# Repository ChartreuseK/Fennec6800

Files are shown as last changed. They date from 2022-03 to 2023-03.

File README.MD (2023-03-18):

# Fennec 6800
A Motorola 6800 Based Expandable Single Board Computer

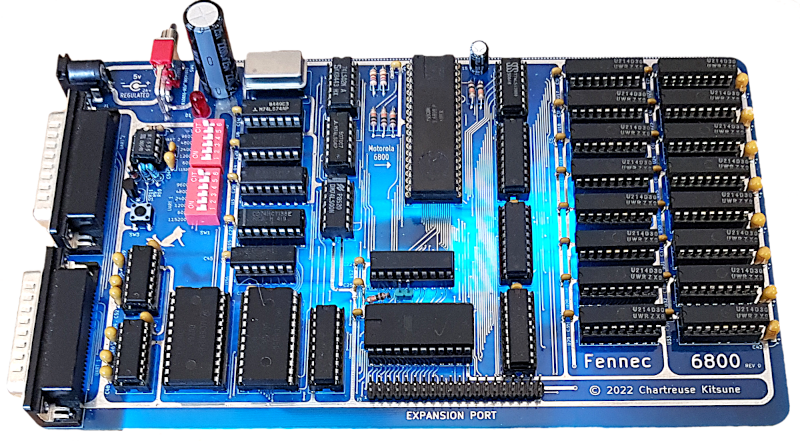
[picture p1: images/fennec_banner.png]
Picture of an Assembled Fennec 6800 Computer


## Introduction
The Fennec 6800 is a Motorola 6800 based single board computer (SBC) created with the inspiration of targeting 1977 components and features. It features an original Motorola 6800 processor running at whopping 921.6kHz, 8kB of the latest 2114 SRAM, 2kB of ROM using the brand new 2716 EPROM, and dual serial ports. An optional 40 pin expansion bus allows for connectivity to other modules, such as the Fennec VTI video terminal interface board, or to create your own attachments.

## Specifications
* Motorola 6800 @ 921.6kHz
* 1-8kB of onboard SRAM using pairs of 2114 (1k x 4 bit) SRAM chips. Using the optional RAM adapter board up to 32kB of RAM can be fitted with minimal modifications
* 2kB, 2716 EPROM containing the Fennec Monitor. Optional support for a 4kB 2732 EPROM
* Dual 6850 ACIA, RS-232 UART connected to dual 25 pin EIA-232 ports in DTE wiring.
* Selectable serial baud rates via DIP switches from 600-9600 baud + 115,200 in default /16 mode, 150-2400+28,800 in /64 mode when configured. Non-standard baud rates are possible using a different master oscillator, but CPU speed will be affected.
* Single rail design. Requires only a 5v regulated source of power.
* 40 pin expansion bus with pre-decoded expansion board select signals, allowing for quite prototyping of custom expansions.
* Beautiful blue PCB with exposed traces for a refined look.
* Compact Board design, only 8.6×5.2 inches!

The Fennec 6800 includes a capable and expandable ROM monitor built in, requiring no tedious toggling of front panel switches to enter and begin executing code. Only a terminal is required to begin making use of the system, simply hook the terminal up to the bottom serial port (furthest from the power jack). This serial port is the local console port in the default system, all traffic is normally routed through this port, though inside the monitor certain commands may be redirected to the auxiliary port located above it.

The monitor provides facilities for examining memory, depositing values into memory, jumping to code in memory, receiving a binary over the XMODEM protocol into RAM, and dumping a block of RAM over the XMODEM protocol. With these facilities and an appropriate host system, program development can be done remotely and loaded into the Fennec to speed up initial system bring-up and testing, or development can be done in the traditional way on paper then loaded in in hexadecimal into the program memory and tested out using the computer.

The monitor also provides support for option ROMs. These option ROM images can be mapped into any of the expansion regions in upper memory starting at a multiple of 0x1000. If detected they can hook into the monitor to provide future expandability and extra features, such as the Fennec VTI board which uses an option ROM to redirect the default terminal from the first serial port to a video display and asci keyboard interface, allowing for standalone use. Future cards may also use this facility to add additional commands such as providing for a rudimentary disk operation system for example.

## Manual
The file Fennec6800_Manual.pdf contains a more comprehensive manual of the Fennec, including some theory of operation as well as assembly hints and guides. Importantly if building a REV 0 board the bodeges required for correct operation are described. The primary bodge required is changing how the data bus buffer is selected, instead of being controlled by only the CPU it is decoded in a way to allow expansion boards to enable the buffer. The KiCAD schematics reflect the changes already made, however the gerbers and rev0 pcb file don't contain the fix.

## BOM 
The complete BOM can be found in either the manual, or in the spreadsheet Fennec6800_BOM.csv 
The BOM contains the reference designators, quantity, a description of the part, as well as one or more suitable Digikey part numbers. The CPU, ACIA/UARTs, and 2716/28C16 EPROM/EEPROM however need to be aquired from secondary sources as they have not been manufactured in some time. The CPU needs to be a MC6800 or direct compatible, note a 6802 has a different pinout and is not drop in compatible. The ACIAs are MC68B50 or similar UARTs, the B variant is not needed for the lower speeds, however a Hitachi 63B50 (2MHz rated) would be required for 115,200 board operation to not be overclocking the chip slightly. This speed however is honestly faster than the Fennec 68000 is really designed for, and at 9600 baud any variant is fine. For the EPROM any speed grade 2716 or 28C16 or equivalent 2kB (8-bit) EPROM/EEPROM is suitable. 2732 EPROMs may also be used, and the extra space can be mapped by installing the jumper next to the ROM socket, however the monitor would need to be reassembled to take advantage of the extra space.

## Burning the ROM
The 2716 EPROM on the Fennec 6800 should be burned with the file `software/monitor/monitor.bin`. This file is in a flat binary format suitable for burning onto a 2kB EPROM. If your program needs Intel HEX or Motorola SREC format it will need to be converted first. The ORG address is F800 (upper 2kB of address space). 

2716 EPROMs are single supply EPROMs, however they need a programmer capable of a 26v programming voltage. The common TL866CS/A is only capable of 21v, and the newer TL866II+ is only capable of 18v max, and won't be able to program the EPROM. For a more convient option there exists the 28C16 EEPROM which is pin compatible and can be programmed with only 5v and is suitable for either TL866 programmer, or even possibly with an Arduino and some custom code. The 28C16 is no-longer newly manufactured but can be fairly readilly sourced. Alternatively using a pin adapter a 28-pin 28C64 (still sold new on Digikey/Mouser from Atmel) can be converted to the 28C16 24-pin pinout. 

## Assembling the Monitor
The monitor source code is designed to be assembled with the cross-platform [AS macro assembler](http://john.ccac.rwth-aachen.de:8000/as/). It may be possible to assemble with other assemblers supporting the 6800, but some changes to the local label syntax may be required. The output of the macro assembler is it's own p file format which can then be converted using p2bin or p2hex to a suitable output format.

    asl -L monitor.asm && p2bin monitor.p
## Expansions

### 62256 RAM Adapter
In the folder Fennec 62256 RAM Adapter you can find a second PCB which allows the use of common and still in production 62256 (32k x 8) SRAM chips in place of the vintage and hard to source 2114 sram that the Fennec is designed for. This board slots into the top two ram sockets as well as the 74LS138 socket to provide the full 8kB of RAM that the board is designed for. Optionally A13 and A14 may be run to this adapter board to give the Fennec 32kB of RAM, more than normally designed for. 

### Fennec VTI
The [Fennec VTI](https://github.com/ChartreuseK/Fennec6800_VTI) is a 64x16 line text terminal interface with parallel ascii keyboard to provide a local terminal for the Fennec. It negates the need for an external serial terminal, or terminal emulator, making the Fennec into a self contained system. Using the extra port on the PIA on this card, combined with protoboard space, also allows it to be used for experimentations and developing hardware.

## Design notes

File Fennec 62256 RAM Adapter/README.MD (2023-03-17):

# Fennec 6800 62256 RAM Adapter

This adapter allows the use of common 62256 32k x 8-bit SRAM chips with the Fennec 6800, replacing the vintage 2114 SRAM chips. The adapter plugs into the top two SRAM sockets as well as the 74LS138 socket (replacing the IC) and provides a full 8kB of SRAM to the Fennec. Optionally wires may be soldered down to the main board to grab A13 and A14 and soldered to the ram adapter. This modification would allow for the maximum of 32kB of RAM to be fitted to the system, more than normally possbile.

BOM:

* 1x 62256 SRAM - DIP 28
* 1x 74LS02 - DIP 14
* 1x 74LS08 - DIP 14
* 3x 0.1uF 50v X7R Ceramic Capacitors 0.1" pin spacing
* 2x 1k ohm 1/4W carbon film resistor, through hole
* 2x 1x40 pin male machine pin breakaway header. 
  * (16 + 18 + 18 + 9) = 61 pins required.
* Optional 1x40 male square pin header for jumpers. 2 + 3 + 3
* Optional 3x jumper shorting connectors
* 2x DIP 14 socket
* 1x DIP 28 wide (0.6") socket

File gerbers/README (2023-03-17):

# Gerbers for Fennec 6800 board
The plainmask suffixed files contain "normal" solder masks, traces are covered in solder mask as with normal PCBs, this is not the intended look for the Fennec but is provided as an option if people wish. This is the output you get when plotting out the gerber files from KiCAD.

The _exposedtraces_ suffixed files have had the _Cu gerber files copied overtop the _Mask gerber files, this results in all traces and copper on the board being exposed, but the rest of the board being covered in solder mask, resulting in the Fennec's unique look. This is the gerbers you probably want if you're recreating it.

# Creating your own gerbers

If you're making changed in KiCAD and want to get this look, simply copy the two Cu gerber files overtop the corresponding mask file. 
eg.
cp Fennec6800-B_cu.gbl Fennec6800-B_Mask.gbs
cp Fennec6800-F_cu.gbl Fennec6800-F_Mask.gbs

If not using protel extensions the file names will be different but the concept is the same. 

Keep in mind that and custom "keep-out" regions on the mask layers will be lost when doing this. A more complex technique of copying the copper paths to the mask layer in KiCAD would need to be done to preserve them, or hand editing of the gerber code. As the Mask layers in gerber files are inverse, ie. the file specifies where NOT to put soldermask, this results in all copper on the board being left exposed with only the bare FR4 part of the board being covered in the solder mask.

If your PCB fab has access to dyed FR4 board, an even better option is then to eliminate the masks entirely, either by communicating with the fab and asking for no solder mask, or in KiCAD adding a "keep out" box that covers the entire board on both Mask layers. This would result in the "true" intention look of the Fennec if you have access to blue dyed FR4 board.

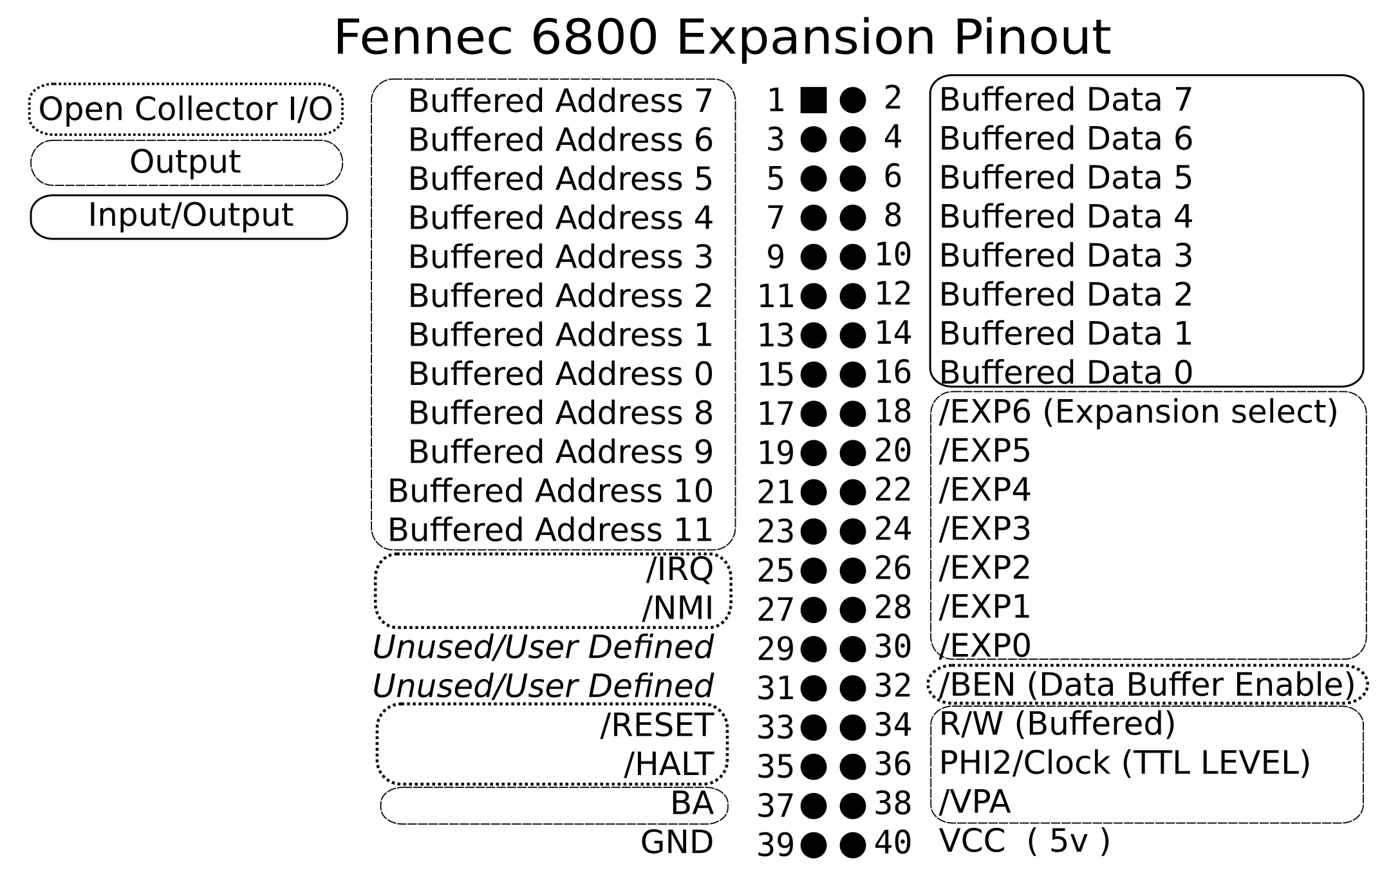
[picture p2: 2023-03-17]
Fennec6800_ExpansionPinout.png

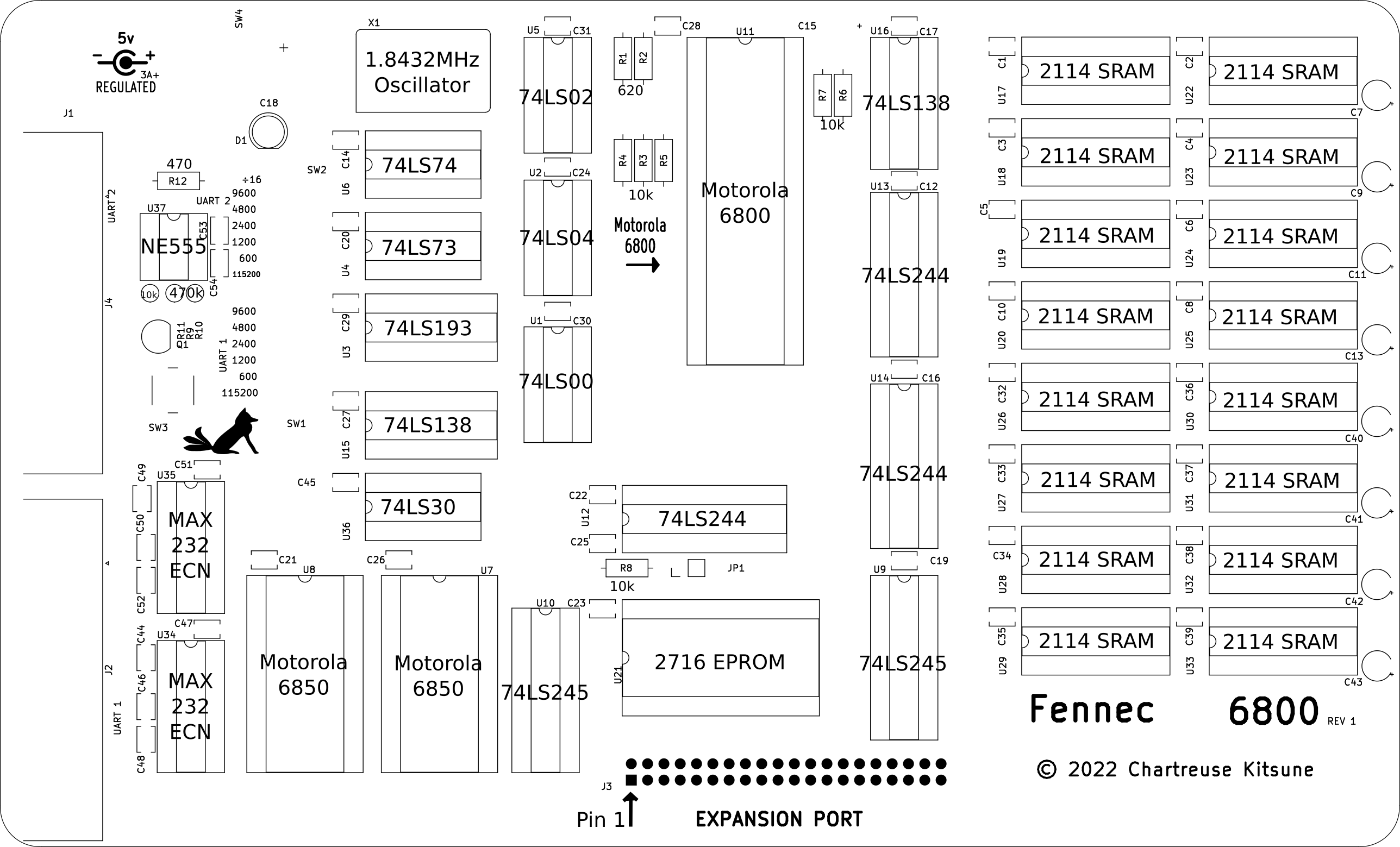
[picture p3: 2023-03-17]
Fennec6800_IC_Diagram.png

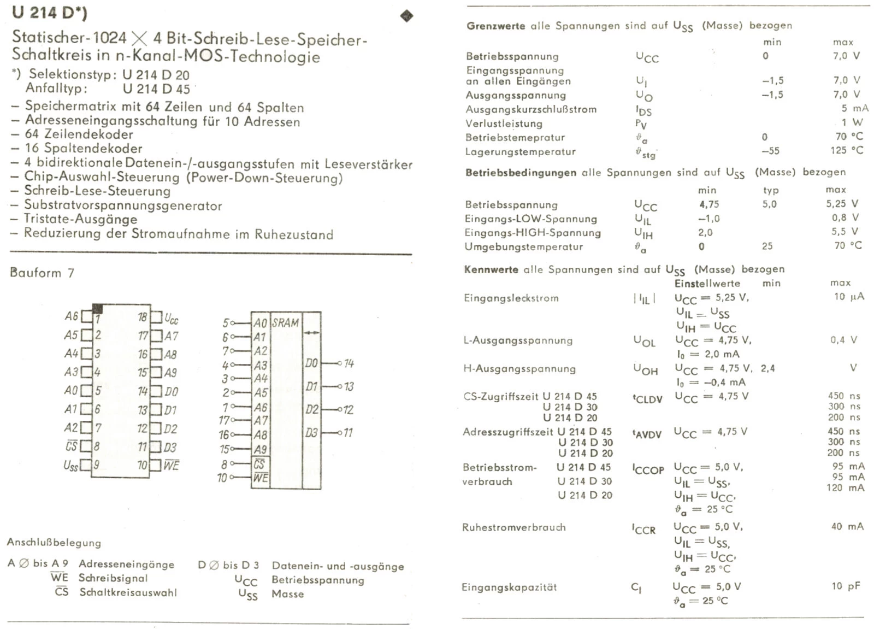
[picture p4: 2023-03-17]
datasheets/U214D.webp

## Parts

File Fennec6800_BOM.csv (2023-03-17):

Reference Designators | Qty. | Part | Digikey Part # | Alternative Digikey Part # (ICs are HCT instead of LS)
C1, C2, C3, C4, C5, C6, C8, C10, C12, C14, C16, C17, C19, C20, C21, C22, C23, C24, C25, C26, C27, C28, C29, C30, C31, C32, C33, C34, C35, C36, C37, C38, C39, C45, C53 | 35 | 0.1uF 50v Ceramic Capacitor, .1” pin pitch | 399-14036-1-ND
C7, C9, C11, C13, C40, C41, C42, C43 | 8 | 10uF 16v Tantalum Capacitor, .1” pin pitch | 478-TAP106K016CRSCT-ND
C15 | 1 | 100uF 16v Aluminum Electrolytic. .1” pin pitch, diameter < 6.3mm | P19632CT-ND
C18 | 1 | 470uF 16v Aluminum Electrolytic. 5mm pin pitch, diameter <13mm | P12375-ND
C44, C46, C47, C48, C49, C50, C51, C52, C56, C55, C56 | 11 | 1.0uF 50v X5R Ceramic Capactior, .1” pin pitch | 445-173257-1-ND | 478-11561-1-ND
D1 | 1 | T1-3/4 (5mm) low-brightness red LED | 160-1707-ND
D2 | 1 | 1N4148 DO-3 diode | 1N4148FS-ND
J1 | 1 | Barrel_Jack, 2.1mm x 5.5mm | CP-202A-ND | CP-102A-ND
J2, J4 | 2 | DB25 Male, right angle board mount. 7.7mm pin edge offset, 9.12mm mounting hole offset | 2057-DB25-PL-24-ND
J3 | 1 | 2x20 0.1” male pin header | 10129381-940002BLF-ND | S2011EC-40-ND
JP1 | 1 | 1x2 0.1” male pin header | 2057-PH1-02-UA-ND | S1011EC-40-ND
Q1 | 1 | 2N3904-AP TO-92 package with stagered center pin | 2N3904BU | 2N3904-AP
R1, R2 | 2 | 620 ohm 1/4W 5% Carbon Film | 620QBK-ND
R3, R4, R5, R6, R7, R8, R13 | 8 | 10k ohm 1/4W 5% Carbon Film | CF14JT10K0CT-ND
R9, R10 | 2 | 470k ohm 1/4W 5% Carbon Film | CF14JT470KCT-ND
R12 | 1 | 470 ohm 1/4W 5% Carbon Film | CF14JT470RCT-ND
SW1, SW2 | 2 | DIP-12, 6 pole DIP switch, 0.3” spacing | 2449-KG06E-ND
SW3 | 1 | 6mm through hole push button | 679-2428-ND
SW4 | 1 | ESWITCH 100SP1T2B4M7QE right angle toggle switch or compatible, SPDT switch | EG5419-ND
U1 | 1 | 74LS00 DIP | 296-1626-ND | 296-1603-5-ND
U2 | 1 | 74LS04 DIP | 296-1629-5-ND | 296-1605-5-ND
U3 | 1 | 74LS193 DIP | 296-1605-5-ND | 296-2142-5-ND
U4 | 1 | 74LS73 DIP | 296-26520-5-ND | 296-3541-5-ND
U5 | 1 | 74LS02 DIP | 296-1627-5-ND | 296-3541-5-ND
U6 | 1 | 74LS74 DIP | 296-1668-5-ND | 296-1605-5-ND
U7, U8 | 2 | MC6850 (68A50/68B50/6350/63A50/63B50) DIP | Vintage, eBay
U9, U10 | 2 | 74LS245 DIP | 296-1655-5-ND | 296-2105-5-ND
U11 | 1 | MC6800 Microprocessor | Vintage, eBay
U12, U13, U14 | 3 | 74LS244 DIP | 296-1653-5-ND | 296-1610-5-ND
U15, U16 | 2 | 74LS138 DIP | 296-1639-5-ND | 296-1608-5-ND
U17, U18, U19, U20, U22, U23, U24, U25, U26, U27, U28, U29, U30, U31, U32, U33 | 16 | P2114 SRAM DIP-18 | Vintage, eBay
U21 | 1 | 2716 EPROM or 28C16 EEPROM | Vintage, eBay
U34, U35 | 2 | MAX232ECN or similar DIP | 296-26139-5-ND
U36 | 1 | 74LS30 DIP | 296-3693-5-ND | 296-2111-5-ND
U37 | 1 | NE555P DIP | 296-NE555P-ND | ICM7555IPAZ-ND
X1 | 1 | 1.8432MHz Full-can (DIP-14) oscillator | X939-ND | 110-MXO45-3C-1M843200-ND
X1 Socket | 1 | DIP-14 (0.3”) crystal socket | ED90428-ND
U7, U8, U21 Socket | 3 | DIP-24 (0.6”) socket | 1175-2554-ND
U9, U10, U12, U13, U14 Socket | 5 | DIP-20 (0.3”) socket | AE9998-ND
U11 Socket | 1 | DIP-40 (0.6”) socket | ED3033-ND
U1, U2, U4, U5, U6, U36 Socket | 6 | DIP-14 (0.3”) socket | 2057-ICS-314-T-ND
U3, U15, U16, U34, U45 | 5 | DIP-16 (0.3”) socket | AE9992-ND
U17, U18, U19, U20, U22, U23, U24, U25, U26, U27, U28, U29, U30, U31, U32, U33 Socket | 16 | DIP-18 (0.3”) socket | 2057-ICS-318-T-ND

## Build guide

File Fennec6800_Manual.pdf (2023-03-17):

# Fennec 6800

## A Motorola 6800 Based Expandable Single Board Computer

## Designed By: Chartreuse

2022-2023

Manual Revision 1.0 – March 2023 | Fennec 6800 User Manual

Dedicated to the Retro Dreams Discord Server for all the help and discussions over the years.

## Introduction

The Fennec 6800 is a Motorola 6800 based single board computer (SBC) created with the inspiration of targeting 1977 components and features. It features an original Motorola 6800 processor running at whopping 921.6kHz, 8kB of the latest 2114 SRAM, 2kB of ROM using the brand new 2716 EPROM, and dual serial ports. An optional 40 pin expansion bus allows for connectivity to other modules, such as the Fennec VTI video terminal interface board, or to create your own attachments.

## Specifications

- Motorola 6800 @ 921.6kHz
- 1-8kB of onboard SRAM using pairs of 2114 (1k x 4 bit) SRAM chips. Using the optional RAM adapter board up to 32kB of RAM can be fitted with minimal modifications
- 2kB, 2716 EPROM containing the Fennec Monitor. Optional support for a 4kB 2732 EPROM
- Dual 6850 ACIA, RS-232 UART connected to dual 25 pin EIA-232 ports in DTE wiring.
- Selectable serial baud rates via DIP switches from 600-9600 baud + 115,200 in default /16 mode, 150-2400+28,800 in /64 mode when configured. Non-standard baud rates are possible using a different master oscillator, but CPU speed will be affected.
- Single rail design. Requires only a 5v regulated source of power.
- 40 pin expansion bus with pre-decoded expansion board select signals, allowing for quite prototyping of custom expansions.
- Beautiful blue PCB with exposed traces for a refined look.
- Compact Board design, only 8.6×5.2 inches!

The Fennec 6800 includes a capable and expandable ROM monitor built in, requiring no tedious toggling of front panel switches to enter and begin executing code. Only a terminal is required to begin making use of the system, simply hook the terminal up to the bottom serial port (furthest from the power jack). This serial port is the local console port in the default system, all traffic is normally routed through this port, though inside the monitor certain commands may be redirected to the auxiliary port located above it.

The monitor provides facilities for examining memory, depositing values into memory, jumping to code in memory, receiving a binary over the XMODEM protocol into RAM, and dumping a block of RAM over the XMODEM protocol. With these facilities and an appropriate host system, program development can be done remotely and loaded into the Fennec to speed up initial system bring-up and testing, or development can be done in the traditional way on paper then loaded in in hexadecimal into the program memory and tested out using the computer.

The monitor also provides support for option ROMs. These option ROM images can be mapped into any of the expansion regions in upper memory starting at a multiple of 0x1000. If detected they can hook into the monitor to provide future expandability and extra features, such as the Fennec VTI board which uses an option ROM to redirect the default terminal from the first serial port to a video display and asci keyboard interface, allowing for standalone use. Future cards may also use this facility to add additional commands such as providing for a rudimentary disk operation system for example.

Manual Revision 1.0 – March 2023 | 2 | Fennec 6800 User Manual

## Design Goals

My goal with the Fennec 6800 was the idea of making a computer mostly within the constraints of the very early days of the personal computer movement. I originally planned to target around 1975 to 1976, however a major difficulty of that era is the available types of EPROMS. The venerable 1702A
EPROM introduced in 1971 only provides 256 bytes of storage, but more importantly requires a +5v and -9v rail to operate, and +10v,+47v, and +59v to program. Without a suitable programmer this chip was right out. Next option was the 2704 and 2708 EPROMs, introduced in 1975 at 512 bytes and 1kB respectively these would be fairly suitable to implement a monitor. However like the 1502 these require split rail power supplies to even operate, +5, -5v, and 12v for both, and 26v to program. Not wanting to require a split rail power system I needed to look forward again. Enter the 2716 EPROM, introduced in 1977 and being one of, if not the first, EPROM to work with a single +5v supply, and giving us a generous 2kB of space.

This set the target date for my system, 1977, two years after the venerable Altair 8800, one year after the Sol-20, and the same year that the personal computer trio launched; the TRS-80, Commodore PET, and the first Apple ][ launching the same year. Now this is a loose goal as I will soon demonstrate, but gives me a focus onto what I want the capabilities to be and roughly how those should be aimed at. One major cheat to this on the board was the use of MAX232 serial level shifters, a chip from 1988. This was more for convenience and not needing to introduce split rail power for the more period MC1488/MC1489 shifters, or discrete transistor circuits also common.

In keeping with the target date, RAM needed to be limited. Now it’s tempting with a modern
homebrew to just slap 64kB or more on these 8-bit systems and be done with it, however in fitting with the era I wanted something a bit more humble. I figured that 8kB was a suitable amount of RAM, with the system being capable of working with as little as 1kB fitted. For RAM I went with the 2114 SRAM chip, also from 1977. While it would not have been the most economical RAM chip of that era, it was the most simple to interface with. It requires only a single rail 5v supply, and no refresh or multiplexing circuitry. Another reason for the choice was that I was able to source twenty of these chips relatively cheaply from an eBay seller and it was part of the inspiration for the project.

Now you may think that only 8kB of RAM seems rather limited, and really it’s not that bad for the era. Sure bigger systems were around, but many of the home computers and kits available at that time would be lucky to have 8kB. The Altair 8800 in bare form shipped with only 256 bytes, though if you were running BASIC you’d likely have at least one 8kB ram expansion for it. Even for 1977, the lowest spec Apple ][ came with a whopping 4kB of RAM, and as RAM was quite expensive, not many people would have opted to max the Apple ][ out with 48kB. The TRS-80 Model 1 also only came with 4kB as standard, same with the PET ][. So 8kB on the Fennec is plenty in line with the competition and other computers of the era, even if RAM prices started falling quickly afterwards.

Part of design was this would be my first homebrew computer created on a PCB in KiCAD without prototyping it on a protoboard or breadboard. Care was put into the schematics and overall design, built on experience with my prior homebrew computer projects and lessons learned from them. This resulted in a computer that required only a small handful of bodge wires to get it working. A resistor was pulled the wrong voltage rail on the ROM. One of the serial baud rates was connected to the wrong point, resulting in the wrong indicated baud, and one bus buffer was connected in a way that made the

Manual Revision 1.0 – March 2023 | 3 | Fennec 6800 User Manual

expansion port unable to drive the bus. The third error being corrected by using a diode and a spare pin on the BUS to create a bus enable input.

In fitting with the design period goals, my aesthetic intentions were to make the board look like some period boards of the time, specifically the blue FR4 with exposed traces look of some Solid State Music and Vector protoboards of the era. Blue dyed FR4 is not really an option at any of the major board houses, especially the cheap ones, however I had learned of a trick from Glitch, who used the concept on his recreation of a Solid State Music board. The trick being to copy the copper layers into the Gerber files of the solder mask layers. This would result in the copper being entirely exposed, with solder mask everywhere but the copper. This is due to the solder mask Gerber files being an inverse mask. Using this with blue solder mask results in the board with some of the appearance of blue dyed FR4, though with a slightly more shiny finish and more translucency of the board. However the end result is simply stunning in appearance.

One downside of course is that all traces are exposed, resulting in more chances of metal contact resulting in a short, or solder splashes shorting some traces. However this can be avoided by being extra careful during soldering, and double checking for shorts after assembling. Shorts can then simply be wicked away with solder braid. As for the former, I’d recommend placing the board in a protective case, perhaps with a clear top to allow the board design to be clearly seen.

Manual Revision 1.0 – March 2023 | 4 | Fennec 6800 User Manual

## Theory of Operation

### Clock Generator

The MC6800 requires two two clock signals, ϕ1 and ϕ2, to be rail-to-rail, non-overlapping inverse

clock signals, ie. 180 degrees out of phase. The tricky part here being the non-overlapping part,

preventing the use of just a simple inverter to put the clocks out of phase. A simple inverter would

satisfy the 180 degrees out of phase part, mostly, but the second clock would be overlapping with the

first by the propagation of a 74LS04 gate delay, approximately 7-15ns.

Motorola recommends the use of the MC6875 clock generator to provide the required ϕ1 and ϕ2 clock

inputs. However this chip is difficult to track down nowadays and would add another obstacle to

building the Fennec by requiring another vintage chip. Furthermore, even in it’s time the chip was

rather expensive, so designers would be apt to avoid it if they didn’t need the additional functionality it

offered besides driving the clock signal. For these reasons I chose to forgo this chip, and instead settled

on driving the clock myself.

To generate these non-overlapping clocks without the MC6875 we need just a simple circuit to

generate a non-overlapping inverted signal. A pair of NOR gates are wired to form a simple RS flip

flop, with a simple square wave clock signal going into the set input. The reset input is connected via

an inverter to the clock signal as well. This inverter between the set and reset inputs helps to insure the

non-overlapping condition through it’s own gate delay. With this the output of the NOR gate connected

to the set input will always change it’s state before that of the one on the reset input. Thus ensuring that

both clock inputs are never high at the same time, the ~10ns gate delay of the 74LS04 providing a

period where both clocks will be low before any rising edge.

### UART decoding

In the name of future expandability, as the /EXP0 is brought out to the bus, the two UARTs are fairly

tightly decoded on the system board, taking up only 16-bytes of the entire address space. While the

upper address space is decoded into 8 equal 4kB regions called EXP6 to EXP0 as well as the ROM

region, it feels appropriate to not waste address space on partial decoding of the UARTs.

The UARTs are thus decoded with a combination of signals. First A11 to A4 are NAND-ed together to

create a signal limiting it to the top 16 bytes of any given 4kB segment, this signal is then inverted

before going to the active-high CS1 chip selects of the 6850 UARTs. The active-low chip select CS2 is

fed by the /EXP0 selection signal, thus now limiting both UARTs to the $EFFx address space. Finally

to differentiate the two UARTs, one is fed A1 on its final CS0 active high chip select, and the other is

fed the inverse of A1 on its CS0 chip select.

This results in a slight partial decoding as the UARTs only require 2 bytes of address space each, but

will be mirrored 4 times within the 16-byte space that they are decoded.

Manual Revision 1.0 – March 2023 | 5 | Fennec 6800 User Manual

### UART Clock Generation

The UART clock rates were an important factor in deciding the overall clock speed of the system. The

CPU speed was desired to be as close to the maximum 1MHz permitted by a plain MC6800 as

possible, however I only wished to use a single oscillator for the entire system. The standard

1.8432MHz baud rate oscillator was thus chosen to be master oscillator for the system. When divided

in half we get a 921.6kHz clock, very close to the maximum 1MHz for the CPU.

1.8432MHz also is extremely useful as a baud rate clock, with no external division and just relying on

the 6850 ACIAs internal /16 mode for asynchronous serial we get 115,200 baud. Too fast for our time

period and liking, but a useful modern serial baud rate. The magic however happens when we further

divide the clock down. First we divide the 921.6kHz CPU clock down by 6. To accomplish this we use

a 74LS73 dual-JK flip flop in a divide by three configuration. The output of this configuration is not a

50% duty cycle however so we divide that again by 2 using a 74LS74 D flip flop to return the duty

cycle to 50%. This brings us to a total of 1.8432MHz / 12 or 153.6kHz. When this baud rate is divided

by 16 in the UART that results in our first usable standard baud rate of 9600.

From 9600 it’s then just a matter of using a 4-bit binary counter to further divide this down into usable

baud rates. 4800, 2400, 1200, and 600 are derived this way. We can also take advantage of the /64

mode of the 6850 UART to get an additional set of 6 baud rates to select form. 115,200 becomes

28,800. 9600 becomes 2400, 4800 becomes 1200, 2400 becomes 600, 1200 becomes 300, and 600

becomes 150. This gives us the standard set of serial baud rates from 150 to 9600 baud to chose from,

in addition to the faster standards of 38,400 and 115,200.

19,200 baud is unfortunately not possible with this clock choice and division circuit as it would require

1.8432MHz / 3 / 16. However we cannot produce the divide by 3 with a 50% duty cycle as required. It

could be generated with a 3.6864MHz oscillator, however this would require another D-flip flop to

divide down the clock to create our 921.6kHz CPU clock.

### ROM decoding

Upon coming out of reset, the Motorola 6800 first fetches its 16-bit reset vector from address

$FFFE/$FFFF it then jumps to the address contained in that vector to begin execution. Because of this

we require ROM to be in the upper most address of our address space. As such the Fennec 6800’s 2kB

ROM is put into the upper most address space. The upper 32kB of address space on the Fennec is

decoded by a 74LS138 3-8 decoder, resulting in 8 equally sized 4kB regions being decoded. The 2716

ROM is assigned the upper most of these, labelled by the select line /ROM.

As the 2716 ROM is only 2kB, it is allowed to mirror itself an additional time in this 4kB space. First it

is visible from $F000 to $F7FF. Secondly an additional identical copy is visible from $F800 to $FFFF.

For the code in the ROM its canonical address is assumed to be the upper $F800-$FFFF mirror.

If a 2732 ROM is fitted, and jumper JP1 fitted, then it will not be mirrored at all, instead spanning the

entire 4kB address space assigned to the ROM. In this case a special version of the monitor ROM will

need to be compiled, either to put the standard version only in the upper 2kB of the ROM, or else

Manual Revision 1.0 – March 2023 | 6 | Fennec 6800 User Manual

modified to know that it is now 4kB long so that the reset and interrupt vectors arrive in the correct

places. If the later option is chosen note that code that relies on the monitor jump table, or any other

fixed entry point into the ROM will need to be patched to work.

Manual Revision 1.0 – March 2023 | 7 | Fennec 6800 User Manual

## Expansion Bus

The Fennec 6800 is equipped with a custom 40-pin expansion bus. This size was chosen to correspond

with easily available 40-pin IDC connectors and ribbon cables. These ribbon cables are commonly

found in old IDE interfaces for IBM-compatible personal computers. Later 80-pin varieties are NOT

compatible as they assume certain pins to be ground. Do not attempt to use an 80-pin IDE cable as a

bus cable.

The bus provides access to a buffered set of 8 data lines. 12 buffered address lines A0 through A11,

corresponding to the size of each expansion area in the memory map. 7 pre-decoded expansion

signals /EXP0 through /EXP6 to allow for rapid development and prototyping of expansion cards. An

assortment of 6800 control signals: BA indicates that the bus is available if the processor is in /HALT

or WAIT. /VPA is a decoded signal where VMA is asserted and PHI2 is high, indicating addresses are

stable and peripherals can drive or read the bus. /HALT can stop the processor and free the bus.

/RESET is bidirectional (open collector) to either reset peripherals from the master reset circuitry on

the CPU board, or to drive reset to reset the processor. /NMI and /INT are open collector inputs to

signal either a non-maskable or maskable interrupt to the processor. E_PHI2 is a buffered TTL level

CPU clock at 921.6kHz, allowing peripherals to synchronize more flexibly than just /VPA or derive

synchronous clocks to the CPU. R_W2 is a buffered R/W signal where a high level indicates read and a

low level a write operation. /BEN is an open collector input to the CPU board indicating that an

external board wishes to have the data buffer enabled. This signal should be driven by a peripheral

board when it senses it has been decoded, it is required to be enabled for both reads and writes to work

to that peripheral. Power and ground are self explanatory, a regulated 5v source and ground reference.

Finally two lines on the buffer are not-connected and reserved for future/user use and expansion to send

signals between multiple peripheral cards, or for adding additional features to the system board.

Manual Revision 1.0 – March 2023 | 8 | Fennec 6800 User Manual

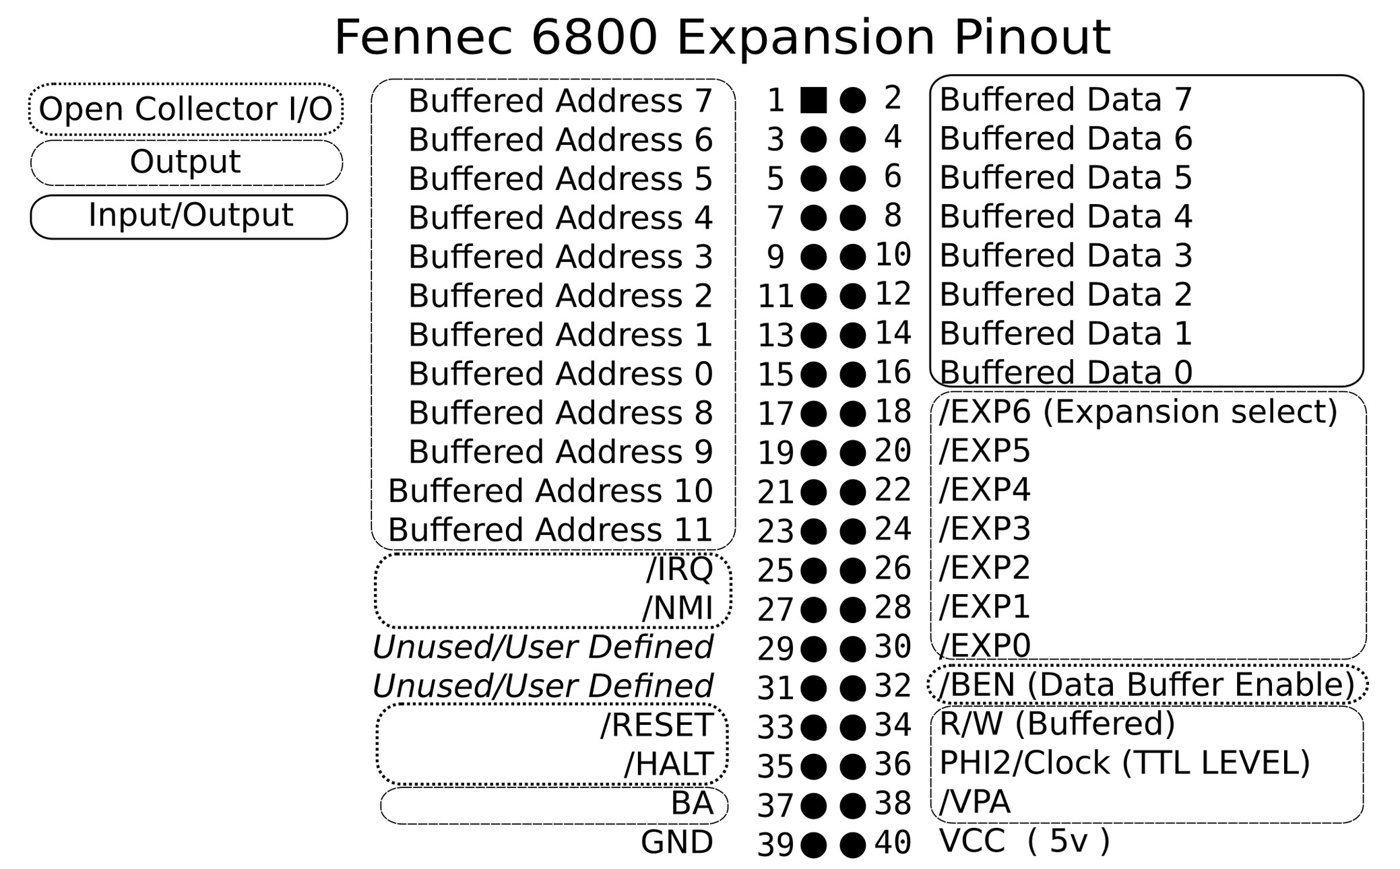
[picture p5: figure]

Manual Revision 1.0 – March 2023 | 9 | Fennec 6800 User Manual

## Assembly

Assembly is rather straight forward but should be accompanied by the schematic or bill of materials to

know where to place the various resistors. I’ve corrected this for my future boards, but this board only

has the reference designators and not the component values marked.

Like other throughole kits I would recommend starting from the shortest components to the tallest

components, and I would personally recommend sockets for the ICs, especially the vintage ones,

though they are not required. My personal assembly order would be to do the IC sockets first, even if

they’re taller than the resistors, but either approach has it’s merits. For the tantalum capacitors to the

side of the RAM, and the two electrolytic capacitors, make sure to get their polarity correct. Both have

their positive side marked on the board, for tantalum capacitors their positive lead is normally marked

with a + sign or stripe on the capacitor, and for electrolytics their negative side is normally marked

with a stripe. If cost is a factor, feel free to omit some of the tantalum capacitors as the number is likely

overkill as I miscalculated the current dram of the SRAM chips (mainly due to only a single pair being

active at any one time).

Before installing R8 near the 2716 RAM please check the bodges section below if you have a REV. 0

board, if you have a REV. 1 board disregard this information.

If you are opting to not install a power switch, connect a decently thick jumper wire from the centre pin

of the switch footprint to the top pin of the 3. Do not connect the wire up to the two mounting holes

near the top edge of the board as this would result in a short circuit.

The CPU must be a Motorola 6800 or pin compatible clone. The later Motorola 6802 is not compatible

as it requires a different clock generation circuit and includes some built in RAM, though with some

bodges it may be possible to adapt, but this is left as an exercise to the reader. The 6801/6803/6805

micro-controller variants are likewise incompatible as they use a different pin-out and multiplexed bus

structure. The Motorola 6809 is also incompatible being a completely different CPU. The rather rare

MOS 6501 CPU would work in the board, however it would require an entirely different ROM to be

made for it. While it’s pin compatible with the Motorola 6800 it is NOT software compatible.

Care should be taken when installing the DIP18 sockets for the 2114 SRAM chips as there are a few

instances where multiple traces are fairly close the pins and I found that this was where I made the only

solder bridge when assembling my original, but this I caught immediately.

Resistors R1 and R2, the pair of 680 ohm resistors to the left of the CPU, are used to help drive the

outputs of the clock generator U5 rail-to-rail to meet the 6800’s specifications. If using a 74HCT32

instead of a 74LS32 these resistors may be omitted entirely. Other logic family substitutions may

require slight changes from the values depending on the current sinking strength of the IC in question.

The value of the resistors should be kept as low as feasible to improve the rise times, up to what is

required by the data-sheet, but need to be high enough to present a voltage below the 6800’s V_IL for

the clock input pins. For the clock lines, the Motorola 6800 data-sheet calls for a rise and fall time of

Manual Revision 1.0 – March 2023 | 10 | Fennec 6800 User Manual

not greater than 100ns, an input low voltage of not greater than 0.4v (above Vss/GND), and an input

high voltage no less than 0.6v below Vcc, a voltage of 4.4v in our case.

If using polarized capacitors, such as electrolytic or tantalum, for the MAX232 ICs charge pump

capacitors, their polarity is not marked on the board and must be installed as following: For C44, C46,

C48, C49, C50, and C52 the positive lead should be installed towards the “top” of the board, if looking

at the board with the Fennec 6800 text upright, ie. with the positive leads going on the side towards pin

1 of their respective IC. C47 and C51 should have the positive lead going to the right side of the board

if viewed the same way, ie with the positive lead going towards pin 16 of their respective MAX232 IC.

The two DB-25 ports are wired for male DB-25 ports such that the device is configured as a DTE

device. If female ports are fitted instead then the device will stick act as a DTE, just with the wrong

polarity connector, for the Fennec to act as a DCE a null-modem adapter is required to swap the Rx and

Tx lines, as well as the CTS and RTS lines. DTS, DCD, and DSR and not connected and thus limited

modem compatibility is available. The 6850 UARTs fitted do have provisions for a DCD line to be

fitted, however no free buffers are available with the MAX232 chips. If desired an additional MAX232

or similar could be dead bugged into the circuit, and the DCD lines hooked up, however no space is

provided for the chip or it’s associated capacitors.

### Required Bodges (REV. 0)

If assembling a REV. 0 version of the board a number of bodges need to be applied for correct

operation. The baud rate bodge is optional as it only affects the 115200 baud rate which is honestly too

fast for the computer in most circumstances. For wiring I recommend 26 or 30 AWG wire wrap wire

(0.4 to 0.25mm wire) for doing the neatest bodges. Wire-wrap wire has thin insulation of Kynar

(PVDF) or sometimes Teflon (PTFE) and is silver plated copper wire, and is ideal for bodges like these.

VPP Resistor on the 2716 EPROM

The original board layout had the 10k resistor from the VPP pin on the 2716 going to ground, however

for correct operation of the ROM it should be going to the 5v rail. Instead of putting the resistor

between the two holes designated for it. Solder one lead to the hole nearest the jumper, and for the

other, bend it 90 degrees and solder it to the top side of the nearby 5v rail. The rail is just to the right of

the ground rail hole that it was originally indicated to be soldered into.

Bus Transceiver for Expansion

This one is a little more involved and requires two additional components. A 1n4148 or similar fast

signal diode, and an additional 10k ohm resistor. Solder the resistor from pin 40 to pin 32 of the

expansion connector. When looking on the back side of the board with the edge connector on the edge

closest to you, pin 40 is the top left most pin, and pin 32 is the pin four positions to the right of it.

Next you need to cut two traces on the board. First is the trace going in to pin 19 of IC U10 (74LS245)

to disconnect the output enable line.

Manual Revision 1.0 – March 2023 | 11 | Fennec 6800 User Manual

Next solder a wire from pin 19 of IC U10 to pin 32 of the expansion connector, where we attached the

resistor to previously.

Next we need to solder a diode to pin 19 of IC U10, keep the leads very short as the other end of this

diode will be otherwise loose and we don’t want it to short to anything else. Solder the cathode (black

stripe) side of the diode to pin 19, and leave the other end in the air. Then solder a wire from the anode

end of the diode that we left floating, to pin 9 of IC U7 (the lower 6850 UART). This connects the

/EXP0 signal to the diode, allowing it to enable the bus buffer again.

High Speed Baud Fix

The 115,200 baud rate selection switch was accidentally connected to CLK rather than FULLCLK,

resulting in the baud rate actually being 57,600. To fix this and match the speed to the label cut the

trace leading to pin 7 of the lower dip switch, leaving the connection to the upper dip switch alone.

Then run a wire from pin 3 of IC U6 (74LS74) to the now isolated pin 7 of the lower dip switch. This

will connect the full 1.8432 MHz clock to the dip switch. This clock rate when divided by 16 in the

UART results in 115,200 baud.

MAX232 Bypass Caps (Optional)

The general Vcc to GND bypass caps for the MAX232 were left out of the rev. 0 board by mistake,

however due to nearly capacitors this has not shown to be an issue at all. However to properly bypass

them a 1uF ceramic capacitor should be installed between Vcc and GND for each the ICs. A 1uF

capacitor should be soldered between pins 15 and 16 on each IC on the bottom of the board.

Manual Revision 1.0 – March 2023 | 12 | Fennec 6800 User Manual

## Software

## Memory Map

The memory map of the Fennec 6800 is rather simple. The lower 32kB of address space from $0000 to

$7FFF is reserved for system RAM, with $0000-$1FFF actually being populated with RAM on a full

8kB system with 16x 2114 SRAMs. When using the optional Fennec 62256 RAM replacement board,

the full 32kB can be mapped with the addition of two bodge wires from the replacement board down to

the CPU socket.

System ROM is mapped from $F000-$FFFF, if the normal 2kB 2716 EPROM is being used then this

comprises of two mirrors at $F000-$F7FF and $F800-$FFFF with the later being used.

The remaining address space is divided into 7 expansion zones labelled EXP0 to EXP6. EXP6 is

mapped at the lowest memory address of $8000, and each expansion section is given 4kB of address

space to make use of. EXP6 goes from $8000-$8FFF, EXP5 from $9000-$9FFF, EXP4 from $A000-

$AFFF, EXP3 from $B000-$BFFF, EXP2 from $C000-CFFF, EXP1 from $D000-$DFFF, and finally

EXP0 from $E000-$EFFF.

EXP0 is partially used by the onboard two 6850 ACIA UARTs. These are mapped at $EFF0-$EFFF,

with with 4 mirrors of each being present, leaving the rest of the address space still free. The canonical

base addresses of each are $EFF0 and $EFF2, each being composed of two addresses for data and

control. See the 6850 ACIA data-sheet for further information on programming the UARTs.

Option ROMs are tested for every 1kB starting from $8000 to $DC00. A valid expansion ROM begins

with the two byte sequence of $F1 $0F the “FLOoF” signature, following this is a 10 byte human

readable name of the option ROM that will be printed to the console when found, followed by 4

reserved bytes. The code of the option ROM when found is executed started immediately after this

signature at offset $10 (16-bytes) into the ROM.

## ROM Monitor

The stock ROM monitor is currently at revision 3.0 and includes support for a number of commands to

make programming possible and allow for ease of transfer of programs to other systems. There are

facilities to both load and retrieve hexadecimal data from RAM, to jump to a specified address, and to

transfer memory contents over XMODEM from either the host to the Fennec, or from the Fennec to the

host. The later two commands are intended to support rapid development on the Fennec when using a

more powerful host system acting as a serial terminal emulator. They could also be used with a modem

line to transfer data from one host to another. The 3.0 revision adds various memory hooks to the BIOS

to allow option ROM code on expansion parts to hook and expand the BIOS allowing for greatly

increased and flexible capabilities. Option ROMs can redirect I/O and also introduce additional

commands into the monitor, and even replace existing commands.

Manual Revision 1.0 – March 2023 | 13 | Fennec 6800 User Manual

### Commands

- E - (E)xamine RAM – Performs a hex dump from between two specified addresses. The dash

between addresses is NOT entered by the user but automatically inserted by the monitor

- eg: * E0000-0010

0000: 00 20 08 20 00 00 DF 46 2C 0E 6F 36 7E FA 08 7E

>

- D – (D)eposit RAM – Allows the user to enter hex data in memory starting at the specified

address. After entering the address the starting address will be displayed and the user can then

start entering bytes. After every byte (2 digits) entered a space will be returned showing the byte

has been entered into RAM. Every 16 bytes a newline and the next address will be displayed

similar to the examine command. Press return or ESC after you are done with entering bytes.

- Eg: * D0100

0100:12 34[esc]

*

- G – (G)oto address – Jumps to the specified address and resumes execution at that point. This is

performed as a subroutine jump, so if a program preserves the monitors stack, it can RTS back

into the monitor. Otherwise it should jump back to the cold start address at $F800 so that the

monitor can resume.

- Eg: * G0100

Program executed at address $0100 starts

- R – (R)ecieve XMODEM – Receives a program using the XMODEM (checksum) protocol

starting at the specified address. After specifying address the user will be prompted to start the

XMODEM transfer on the remote computer. At this point start the transfer and when completed

you will be returned to the monitor prompt. If the prompt is not visible, try hitting ESC to get it

to reprint. The Fennec will send a NAK approximately every 3 seconds waiting for the other

end to begin it’s transfer. It also includes retries, attempting to contact the sender 10 times

before giving up after an error or lack of acknowledgement. If 10 retries pass it will output

TIMEOUT to the console and return to the monitor to indicate the error.

- Eg: * R0100

SEND FILE NOW

User starts XMODEM transfer in their serial terminal emulator program

*

- S – (S)end XMODEM – Sends a block of memory using XMODEM (checksum) from between

the two specified addresses. After specifying the second address, the user will be prompted to

start an XMODEM receive on their terminal. At this point, start the transfer and when

completed you will be returned to the monitor prompt. If the prompt is not visible, try hitting

ESC to get it to reprint. The send command currently does not feature any timeout protection

Manual Revision 1.0 – March 2023 | 14 | Fennec 6800 User Manual

and instead relies on the user and the status of the other end to detect that something has gone

wrong in the transfer, if the transfer is locked up the user must press the reset button to return to

the monitor.

- Eg: * S0100-0200

RECV FILE NAME

User starts XMODEM receive in their serial terminal emulator program

*

### Callable Monitor Routines

The monitor program for the Fennec is ever changing, and proper code should not rely on addresses

within it of its routines to stay at fixed addresses. However a jump table of useful functions is kept near

the beginning of the ROM at a fixed address for user programs to call. This table is used to initialize

the RAM controllable routines by the monitor and thus contains the serial port 0 and 1 input and output

functions, as well as a non-blocking version of the serial in routines for both. If the user program

wishes to use the controllable devices of CON and AUX, they should instead use the RAM resident

jump table of the controllable routines, see the section Controllable Routines for more information.

- S0IN - $F803 – Serial Port 0 (lower port) blocking read character. Returns the value received in

the A register. Corrupts the B register.

- S0OUT - $FB06 – Serial Port 0 (lower port) write character routine, blocks until character is

sent. Value to send is passed in the A register. Corrupts the B register

- S0IN_NB - $FB09 – Serial Port 0 non-blocking read character. If a character is available in the

UART, returns the character in A with the zero flag cleared, otherwise returns 0 in A with the

zero flag set. Corrupts the B register.

- S1IN - $F80C – Serial Port 1 (upper port) blocking read character. Returns the value received in

the A register. Corrupts the B register.

- S1OUT - $FB0F – Serial Port 1 write character routine, blocks until character is sent. Value to

send is passed in the A register. Corrupts the B register

- S1IN_NB - $FB12 – Serial Port 1 non-blocking read character. If a character is available in the

UART, returns the character in A with the zero flag cleared, otherwise returns 0 in A with the

zero flag set. Corrupts the B register.

- DDEVIN - $FB15 – Not recommended, use controllable routine DEVIN instead
- DDEVOUT - $FB18 – Not recommended, use controllable routine DEVOUT instead
- DDEVINNB - $FB1B – Not recommended, use controllable routine DEVINNB instead
Manual Revision 1.0 – March 2023 | 15 | Fennec 6800 User Manual

### Controllable Routines

In order to allow for expandability of the monitor ROM by option ROMs the Fennec makes use of so-

called controllable routines. This is essentially a jump table of I/O routines used by the monitor that are

stored in volatile RAM. Using these an option ROM or user program can change where the routines

point to such that the monitor will use a different I/O device for user interactions.

The controllable routines define two virtual devices, the CON and the AUX device. By default the

CON device is set to serial port 0, and the AUX device is set to serial port 1.

The CON device is designed to be for the user facing communication device, it is where user input is

expected and data to the user is output. An example of this is the monitor prompt itself, the * prompt is

written to this device, user input is received from it and echoed back to it, and the command results are

output to it. If connected, the Fennec VTI module will take over this CON function, changing the

device so that output is written to the video display (emulating a serial terminal) and input is from a

connected parallel ASCII keyboard.

The AUX device is designed for supplemental functions not strictly dealing with user input. By default

this device is used for the XMODEM commands. However user software may use this device as seen

fit, for example it may be used as a modem line for connecting to other systems without having to

resort to direct serial port access. It may also be used for a serial printer; a parallel printer could also be

used with a suitable expansion card.

Besides the AUX and CON devices and their functions a routine is also provided to address arbitrary

devices by number. These routines take a device number as an argument and route the output to the

appropriate device. The first 4 devices are specified by the monitor and should be respected by all

option ROMS implementing this function. These devices are the CON device, the AUX device, serial

port 0, and serial port 1 in order. Further devices greater than this may be implemented by either option

ROMs or user programs.

For all controllable routines it is expected that registers A and B may be changed by the routine (caller

saved), while IX and SP are to be preserved by the routine (callee saved). Arguments are passed in A,

and the return value is also in A. Flags may be set by the routines on return, such is the case with the

non-blocking variants of the various IN functions.

- CONIN - $000C – Blocking get character routine for the CON device. Result in A
- CONOUT - $000F – Blocking put character routine for the CON device. Character to send in A
- CONINNB - $0012 – Non-blocking get character routine for the CON device. If a character is

available from the device, returns the character in A with the zero flag cleared, otherwise returns

0 in A with the zero flag set.

- AUXIN - $00015 – Blocking get character routine for the AUX device. Result in A
- AUXOUT - $0018 – Blocking put character routine for the AUX device. Character to send in A
Manual Revision 1.0 – March 2023 | 16 | Fennec 6800 User Manual

- AUXINNB - $001B – Non-blocking get character routine for the AUX device. If a character is

available from the device, returns the character in A with the zero flag cleared, otherwise returns

0 in A with the zero flag set.

- DEVIN - $0001E – Blocking get character routine for the device selected by B. Result in A
- DEVOUT - $0021 – Blocking put character routine for the device selected by B. Character to

send in A

- DEVINNB - $0024 – Non-blocking get character routine for the device selected by B. If a

character is available from the device, returns the character in A with the zero flag cleared,

otherwise returns 0 in A with the zero flag set.

For the three DEV calls the following devices are defined by the monitor ROM and must be respected

by replacement functions:

- 0 – The CON device
- 1 – The AUX device
- 2 – Serial Port 0
- 3 – Serial Port 1

Devices 4 and up may be defined by option ROMs or user programs at their will. See the manual for a

given board to know which devices it defines.

Manual Revision 1.0 – March 2023 | 17 | Fennec 6800 User Manual

## Bill of Materials

Ceramic Capacitors

- 35x 0.1uF 50v X7R with 0.1” (2.54mm) lead spacing
- 11x 1uF 50v X7R with 0.1” (2.54mm) lead spacing. 10 for MAX232 charge-pumps, 1 for 555

reset circuit.

Tantalum Capacitors/Low ESR Electrolytics

- 8x 10uF 16v with 0.1” (2.54mm) lead spacing. Max diameter/width of 5mm.

Aluminum Electrolytics

- 1x 470uF 16v with 5mm lead spacing, max diameter of 13mm. Value not critical, can be larger,

my original prototype used a rather tall 2200uF capacitor in this place.

- 1x 100uF 16v with 2.5mm lead spacing, max diameter of 6.3mm. Don’t use too high of

diameter of capacitor or it may interfere with 62256 ram adapter board or card rails when

mounting.

Sockets

- 16x DIP18 sockets (for 2114 SRAM). If using the 62256 RAM adapter only 3 are required.
- 6x DIP14 sockets
- 5x DIP16 sockets
- 5x DIP20 sockets (0.3” wide)
- 3x DIP24 wide socket (0.6” wide)
- 1x DIP40 wide socket (0.6” wide) for CPU
- 1x DIP8 socket for 555
- 1x DIP14 crystal socket (only 4 corner pins fitted) for main oscillator

Connectors

- 2x D-sub DB-25 male board mount sockets with 7.7mm pin edge offset and 9.12mm mounting

hole offset, or compatible.

- 1x 2.1mm x 5.5mm barrel jack. May be substituted to match your desired regulated 5v power

## supply

- 1x 2x20 0.1” male pin header. I recommend getting a full 2x40 and cutting it in half.
- 1x 1x2 0.1” male pin header. I recommend getting a full 1x40 pin header and cutting to size,

it’ll end up cheaper.

Manual Revision 1.0 – March 2023 | 18 | Fennec 6800 User Manual

Resistors

- 8x 10k 1/4W carbon film resistors.
- 2x 620 ohm 1/4W carbon film resistors
- 2x 470k ohm 1/4W carbon film resistors
- 1x 470 ohm 1/4W carbon film resistor (for power LED, use higher value if using a high

brightness led)

Diodes

- 1x 1n4148 or similar small signal high speed diode
- 1x 5mm LED. Colour of your own preference or choosing but a deep red low brightness LED

recommended.

Transistors

- 1x 2n3904 or p2n222 in TO-92 package with a staggered centre pin.

Switches

- 1x 6mm through hole, 4 pin push button switch for reset
- 1x ESWITCH 100SP1T2B4M7QE right angle toggle switch or compatible for power
- 2x 6 pin DIP switches (DIP-12 0.3” spacing) for baud rate selection. A wire link may be used

instead for fixed baud rate operation.

ICs

- 1x Motorola 6800 processor, any speed grade 1MHz or higher
- 1x 1.8432MHz DIP-14 (full can) oscillator
- 1x 2716 EPROM or 28C16 EEPROM or compatible, a 2732 will also work, 2764 may be used

with a 28 to 24 pin EPROM adapter.

- 2x 6850 UARTs. For 115,200 baud operation (not recommended) a 68B50 or better is required,

and even a 68B50 is slightly out of spec running at 1.8432MHz input clock over its rated

1.5MHz, a 2MHz rated Hitachi 63B50 or similar is required to be fully in spec at that speed.

- 2x MAX232 UART line drivers
- 16x 2114 1k x 4-bit SRAM. Installed in pairs, up to 8 banks.
- 4x 74LS244 octal-bus drivers
- 2x 74LS245 octal-bus transceivers
- 1x 74LS193 4-bit counter
Manual Revision 1.0 – March 2023 | 19 | Fennec 6800 User Manual

- 1x 74LS74 dual D-flip flop
- 1x 74LS73 dual JK-flip flop
- 1x 74LS02 quad NOR gate
- 1x 74LS04 hex inverter
- 1x 74LS00 quad NAND gate
- 1x 74LS30 8-input NAND gate
- 2x 74LS138 3-8 decoder
- 1x 555 timer
Manual Revision 1.0 – March 2023 | 20 | Fennec 6800 User Manual

### BOM Table

Reference Designators | Qty. | Part | Digikey Part # | Alternative Digikey Part # (ICs are HCT instead of LS)
C1, C2, C3, C4, C5, C6, C8, C10, C12, C14, C16, C17, C19, C20, C21, C22, C23, C24, C25, C26, C27, C28, C29, C30, C31, C32, C33, C34, C35, C36, C37, C38, C39, C45, C53 | 35 | 0.1uF 50v Ceramic Capacitor, .1” pin pitch | 399-14036-1-ND
C7, C9, C11, C13, C40, C41, C42, C43 | 8 | 10uF 16v Tantalum Capacitor, .1” pin pitch | 478-TAP106K016CRSCT-ND
C15 | 1 | 100uF 16v Aluminum Electrolytic. .1” pin pitch, diameter < 6.3mm | P19632CT-ND
C18 | 1 | 470uF 16v Aluminum Electrolytic. 5mm pin pitch, diameter <13mm | P12375-ND
C44, C46, C47, C48, C49, C50, C51, C52, C56, C55, C56 | 11 | 1.0uF 50v X5R Ceramic Capacitor, .1” pin pitch | 445-173257-1-ND | 478-11561-1-ND
D1 | 1 | T1-3/4 (5mm) low-brightness red LED | 160-1707-ND
D2 | 1 | 1N4148 DO-3 diode | 1N4148FS-ND
J1 | 1 | Barrel_Jack, 2.1mm x 5.5mm | CP-202A-ND | CP-102A-ND
J2, J4 | 2 | DB25 Male, right angle board mount. 7.7mm pin edge offset, 9.12mm mounting hole offset | 2057-DB25-PL-24-ND
J3 | 1 | 2x20 0.1” male pin header | 10129381-940002BLF-ND | S2011EC-40-ND
JP1 | 1 | 1x2 0.1” male pin header | 2057-PH1-02-UA-ND | S1011EC-40-ND
Q1 | 1 | 2N3904-AP TO-92 package with staggered centre pin | 2N3904BU | 2N3904-AP
R1, R2 | 2 | 620 ohm 1/4W 5% Carbon Film | 620QBK-ND
R3, R4, R5, R6, R7, R8, R13 | 8 | 10k ohm 1/4W 5% Carbon Film | CF14JT10K0CT-ND
R9, R10 | 2 | 470k ohm 1/4W 5% Carbon Film | CF14JT470KCT-ND
R12 | 1 | 470 ohm 1/4W 5% Carbon Film | CF14JT470RCT-ND
SW1, SW2 | 2 | DIP-12, 6 pole DIP switch, 0.3” spacing | 2449-KG06E-ND
SW3 | 1 | 6mm through hole push button | 679-2428-ND
SW4 | 1 | ESWITCH 100SP1T2B4M7QE right angle toggle switch or compatible, SPDT switch | EG5419-ND
U1 | 1 | 74LS00 DIP | 296-1626-ND | 296-1603-5-ND
U2 | 1 | 74LS04 DIP | 296-1629-5-ND | 296-1605-5-ND
U3 | 1 | 74LS193 DIP | 296-1605-5-ND | 296-2142-5-ND
U4 | 1 | 74LS73 DIP | 296-26520-5-ND | 296-3541-5-ND
U5 | 1 | 74LS02 DIP | 296-1627-5-ND | 296-3541-5-ND
U6 | 1 | 74LS74 DIP | 296-1668-5-ND | 296-1605-5-ND
U7, U8 | 2 | MC6850 (68A50/68B50/6350/63A50/63B50) DIP | Vintage, eBay
U9, U10 | 2 | 74LS245 DIP | 296-1655-5-ND | 296-2105-5-ND
U11 | 1 | MC6800 Microprocessor | Vintage, eBay
U12, U13, U14 | 3 | 74LS244 DIP | 296-1653-5-ND | 296-1610-5-ND
U15, U16 | 2 | 74LS138 DIP | 296-1639-5-ND | 296-1608-5-ND
U17, U18, U19, U20, U22, U23, U24, U25, U26, U27, U28, U29, U30, U31, U32, U33 | 16 | P2114 SRAM DIP-18 | Vintage, eBay
U21 | 1 | 2716 EPROM or 28C16 EEPROM | Vintage, eBay
U34, U35 | 2 | MAX232ECN or similar DIP | 296-26139-5-ND
U36 | 1 | 74LS30 DIP | 296-3693-5-ND | 296-2111-5-ND
U37 | 1 | NE555P DIP | 296-NE555P-ND | ICM7555IPAZ-ND
X1 | 1 | 1.8432MHz Full-can (DIP-14) oscillator | X939-ND | 110-MXO45-3C-1M843200-ND
Manual Revision 1.0 – March 2023 | 21 | Fennec 6800 User Manual

Reference Designators | Qty. | Part | Digikey Part # | Alternative Digikey Part # (ICs are HCT instead of LS)
X1 Socket | 1 | DIP-14 (0.3”) crystal socket | ED90428-ND
U7, U8, U21 Socket | 3 | DIP-24 (0.6”) socket | 1175-2554-ND
U9, U10, U12, U13, U14 Socket | 5 | DIP-20 (0.3”) socket | AE9998-ND
U11 Socket | 1 | DIP-40 (0.6”) socket | ED3033-ND
U1, U2, U4, U5, U6, U36 Socket | 6 | DIP-14 (0.3”) socket | 2057-ICS-314-T-ND
U3, U15, U16, U34, U45 | 5 | DIP-16 (0.3”) socket | AE9992-ND
U17, U18, U19, U20, U22, U23, U24, U25, U26, U27, U28, U29, U30, U31, U32, U33 Socket | 16 | DIP-18 (0.3”) socket | 2057-ICS-318-T-ND
Manual Revision 1.0 – March 2023 | 22 | Fennec 6800 User Manual

## IC Layout Diagram

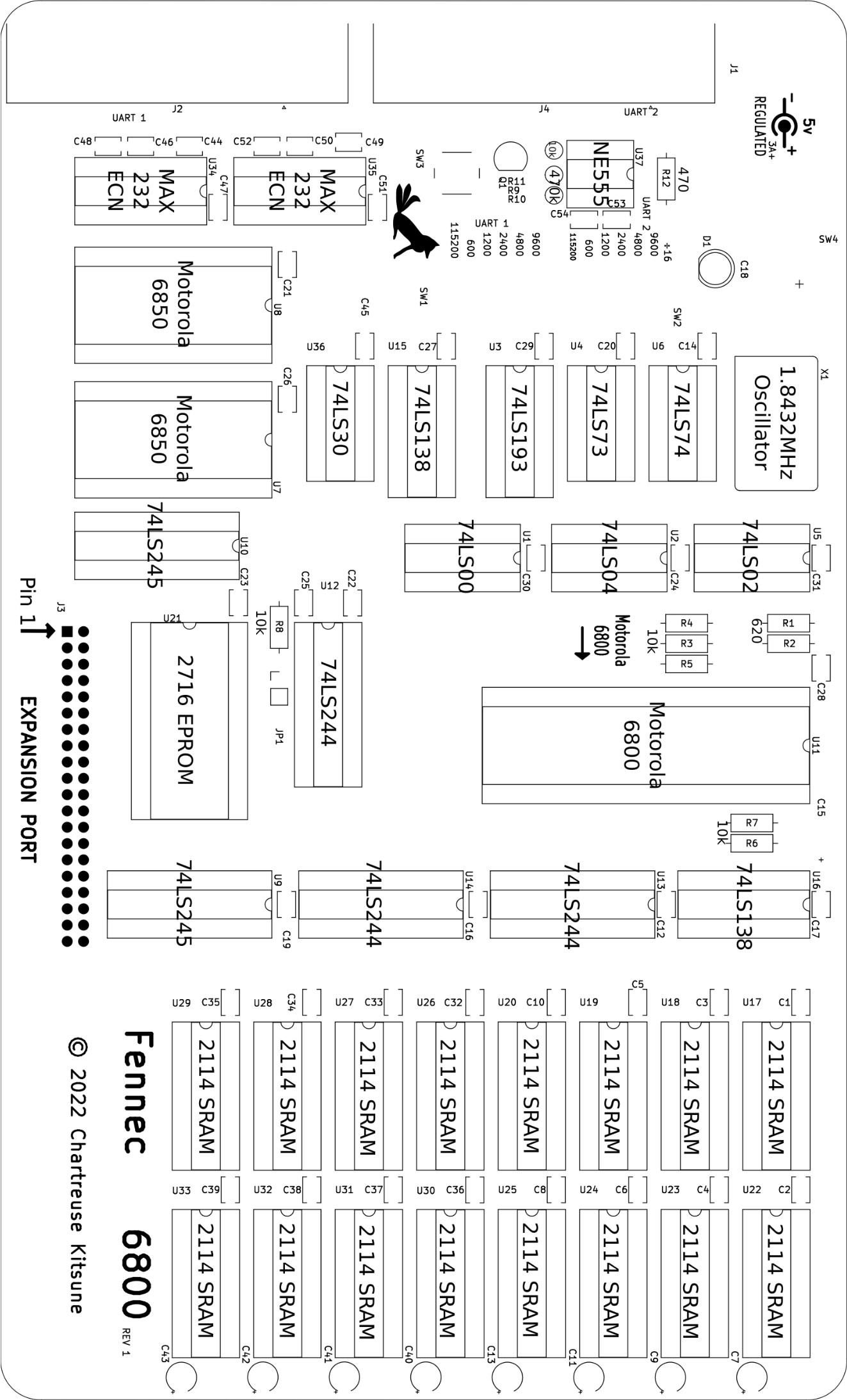
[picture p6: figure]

Manual Revision 1.0 – March 2023 | 23 | Fennec 6800 User Manual

## Schematic

For the most up to date schematics, check out the KiCAD project in the repository. These schematics

are up to date as of REV 1 or REV 0 with bodges applied.

Manual Revision 1.0 – March 2023 | 24 | Fennec 6800 User Manual

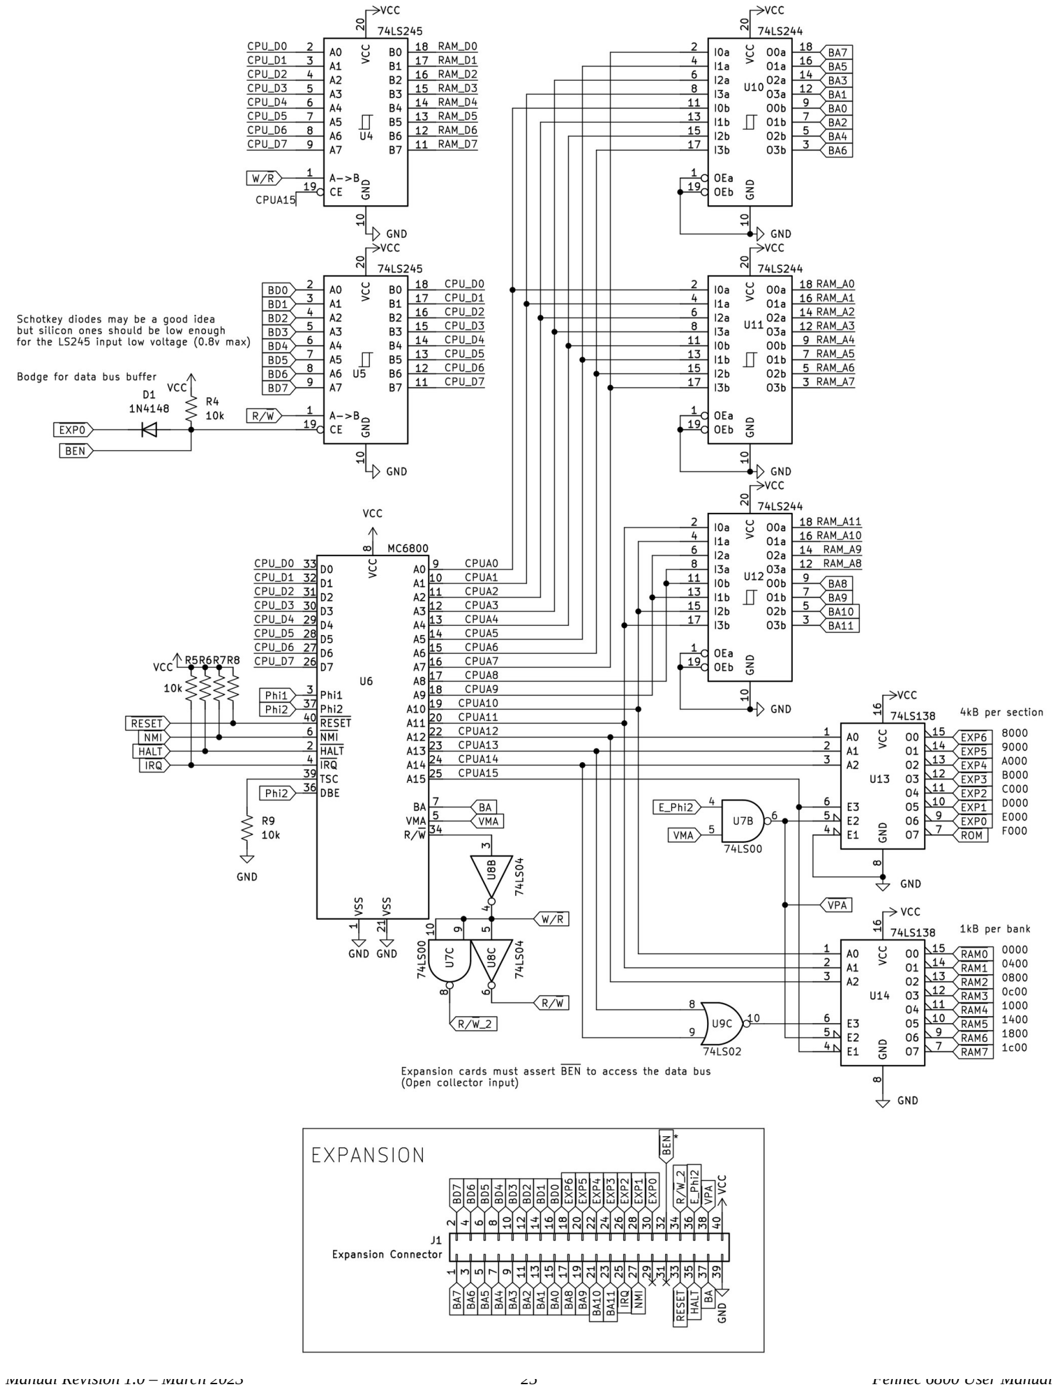
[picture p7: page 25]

Manual Revision 1.0 – March 2023 | 25 | Fennec 6800 User Manual

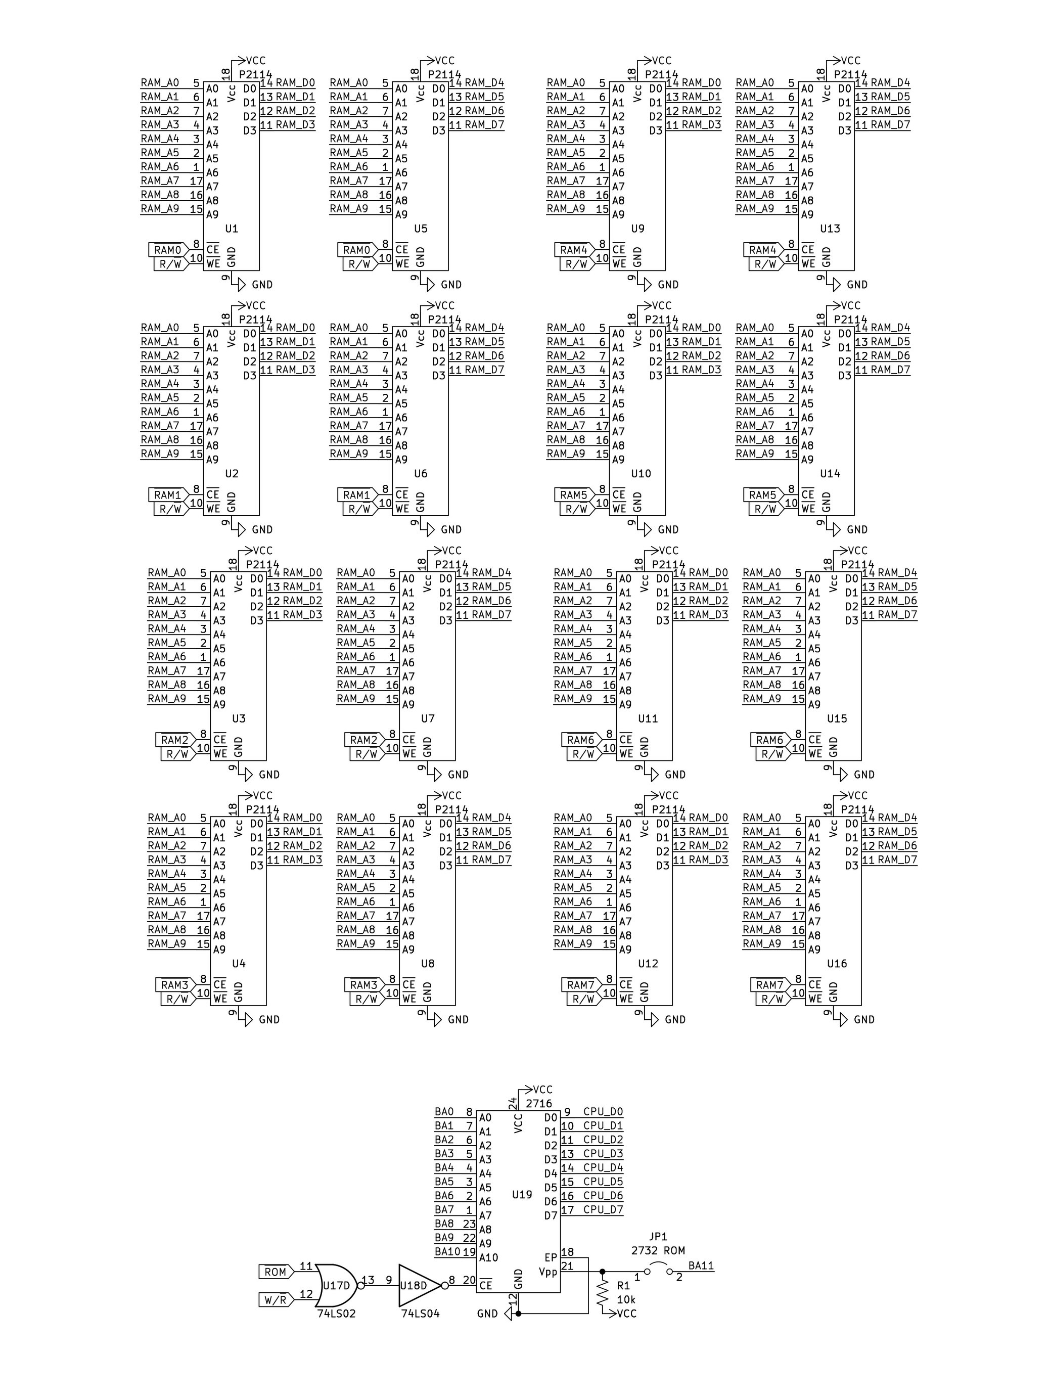
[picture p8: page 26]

Manual Revision 1.0 – March 2023 | 26 | Fennec 6800 User Manual

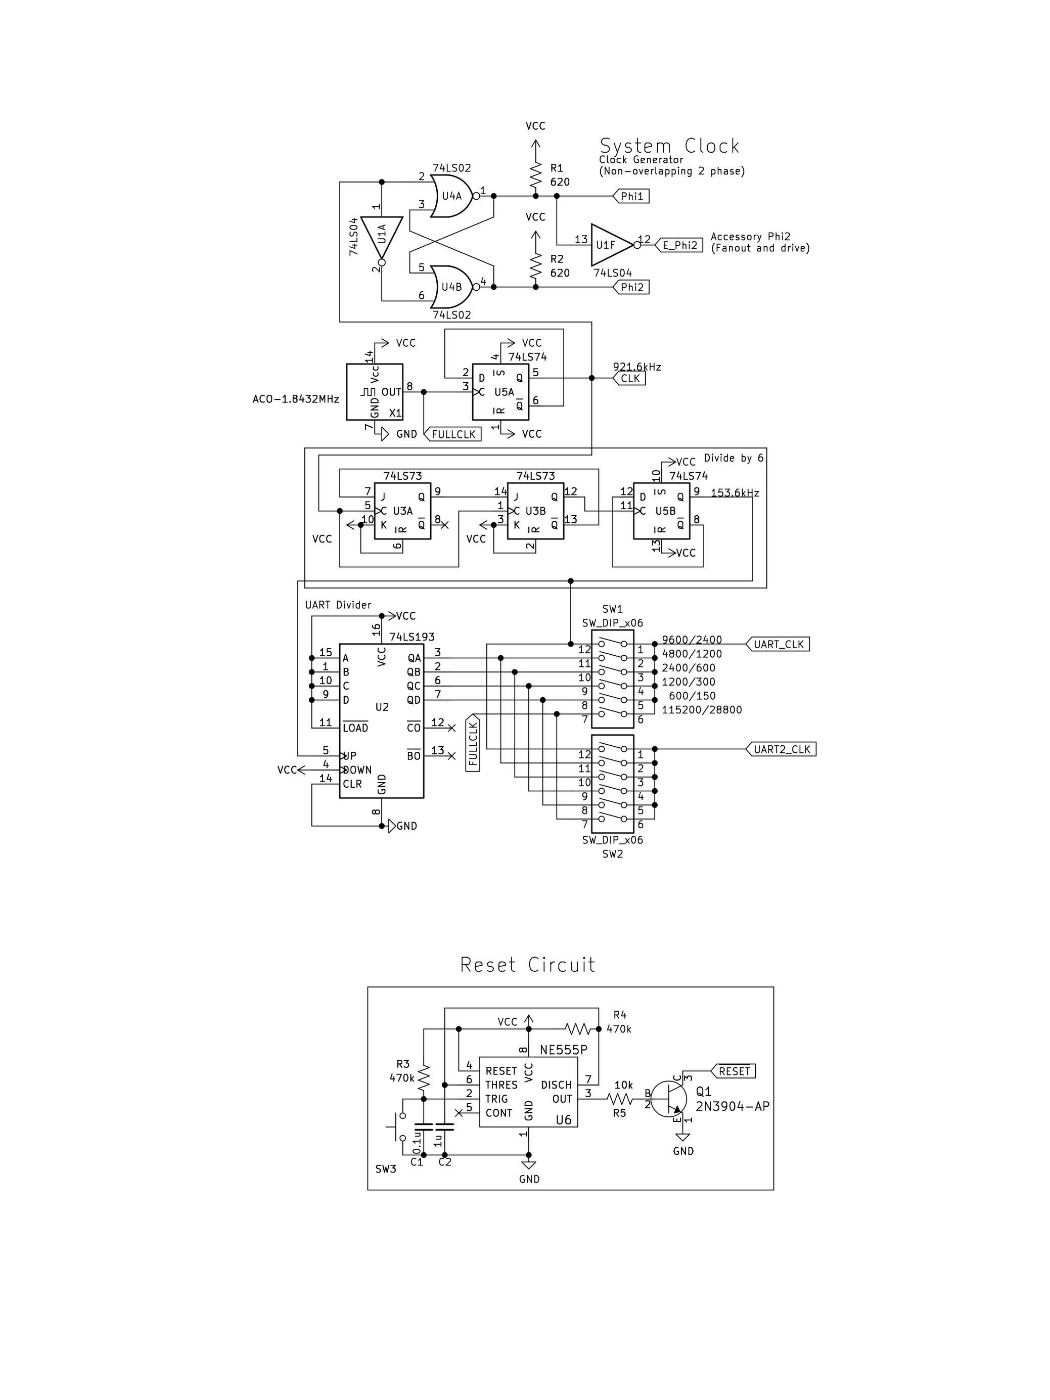
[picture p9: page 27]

Manual Revision 1.0 – March 2023 | 27 | Fennec 6800 User Manual

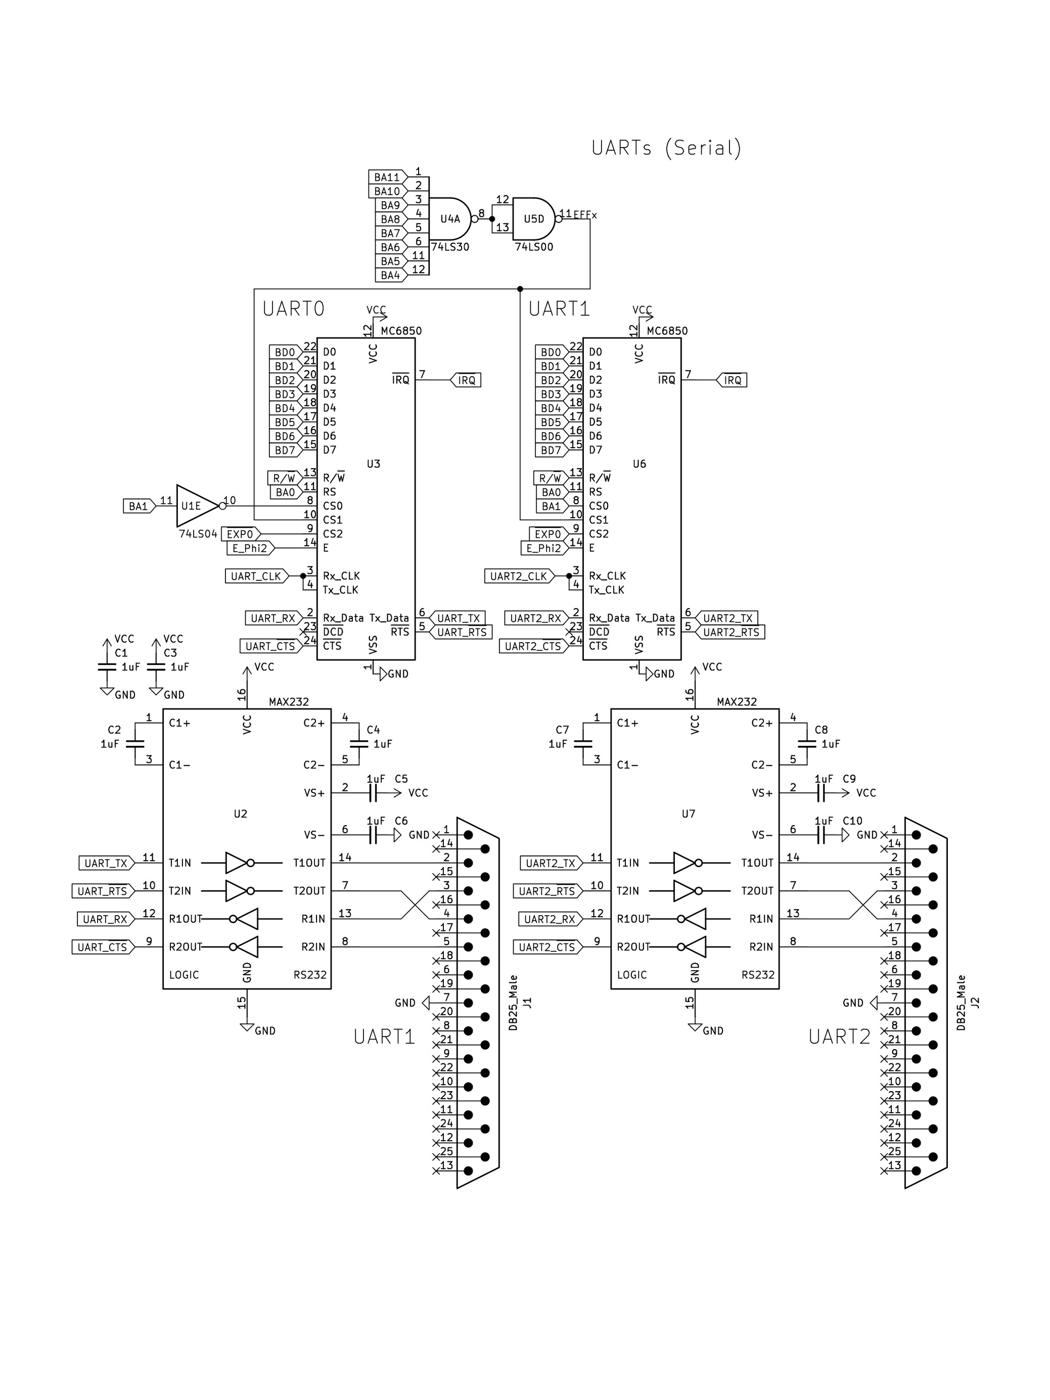
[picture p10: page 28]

Manual Revision 1.0 – March 2023 | 28 | Fennec 6800 User Manual

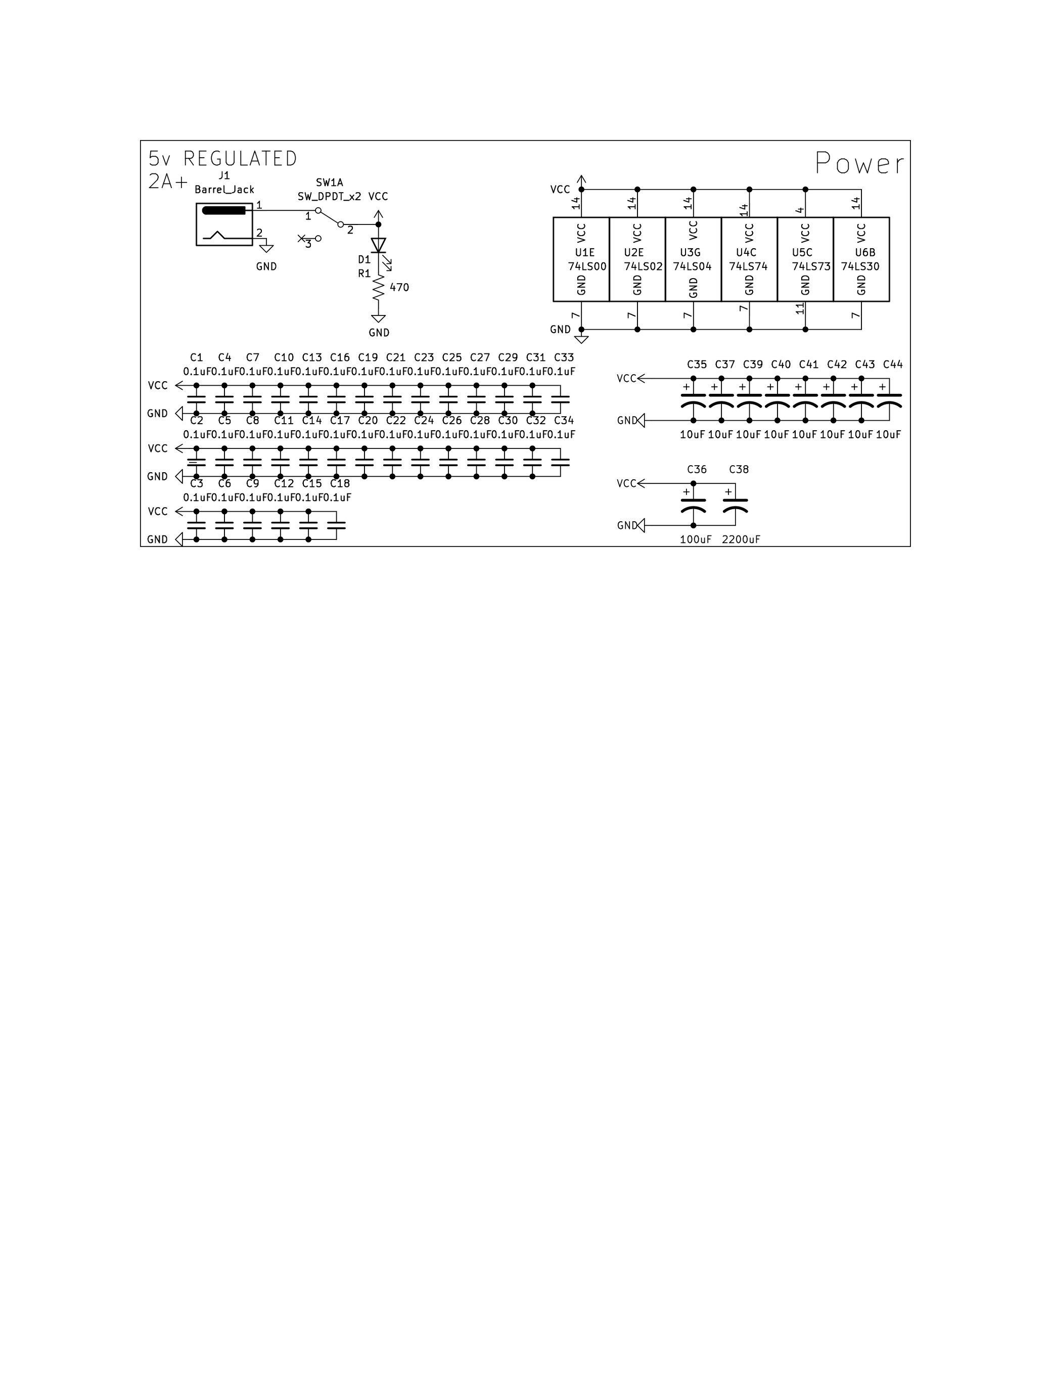
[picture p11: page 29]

Manual Revision 1.0 – March 2023 | 29 | Fennec 6800 User Manual

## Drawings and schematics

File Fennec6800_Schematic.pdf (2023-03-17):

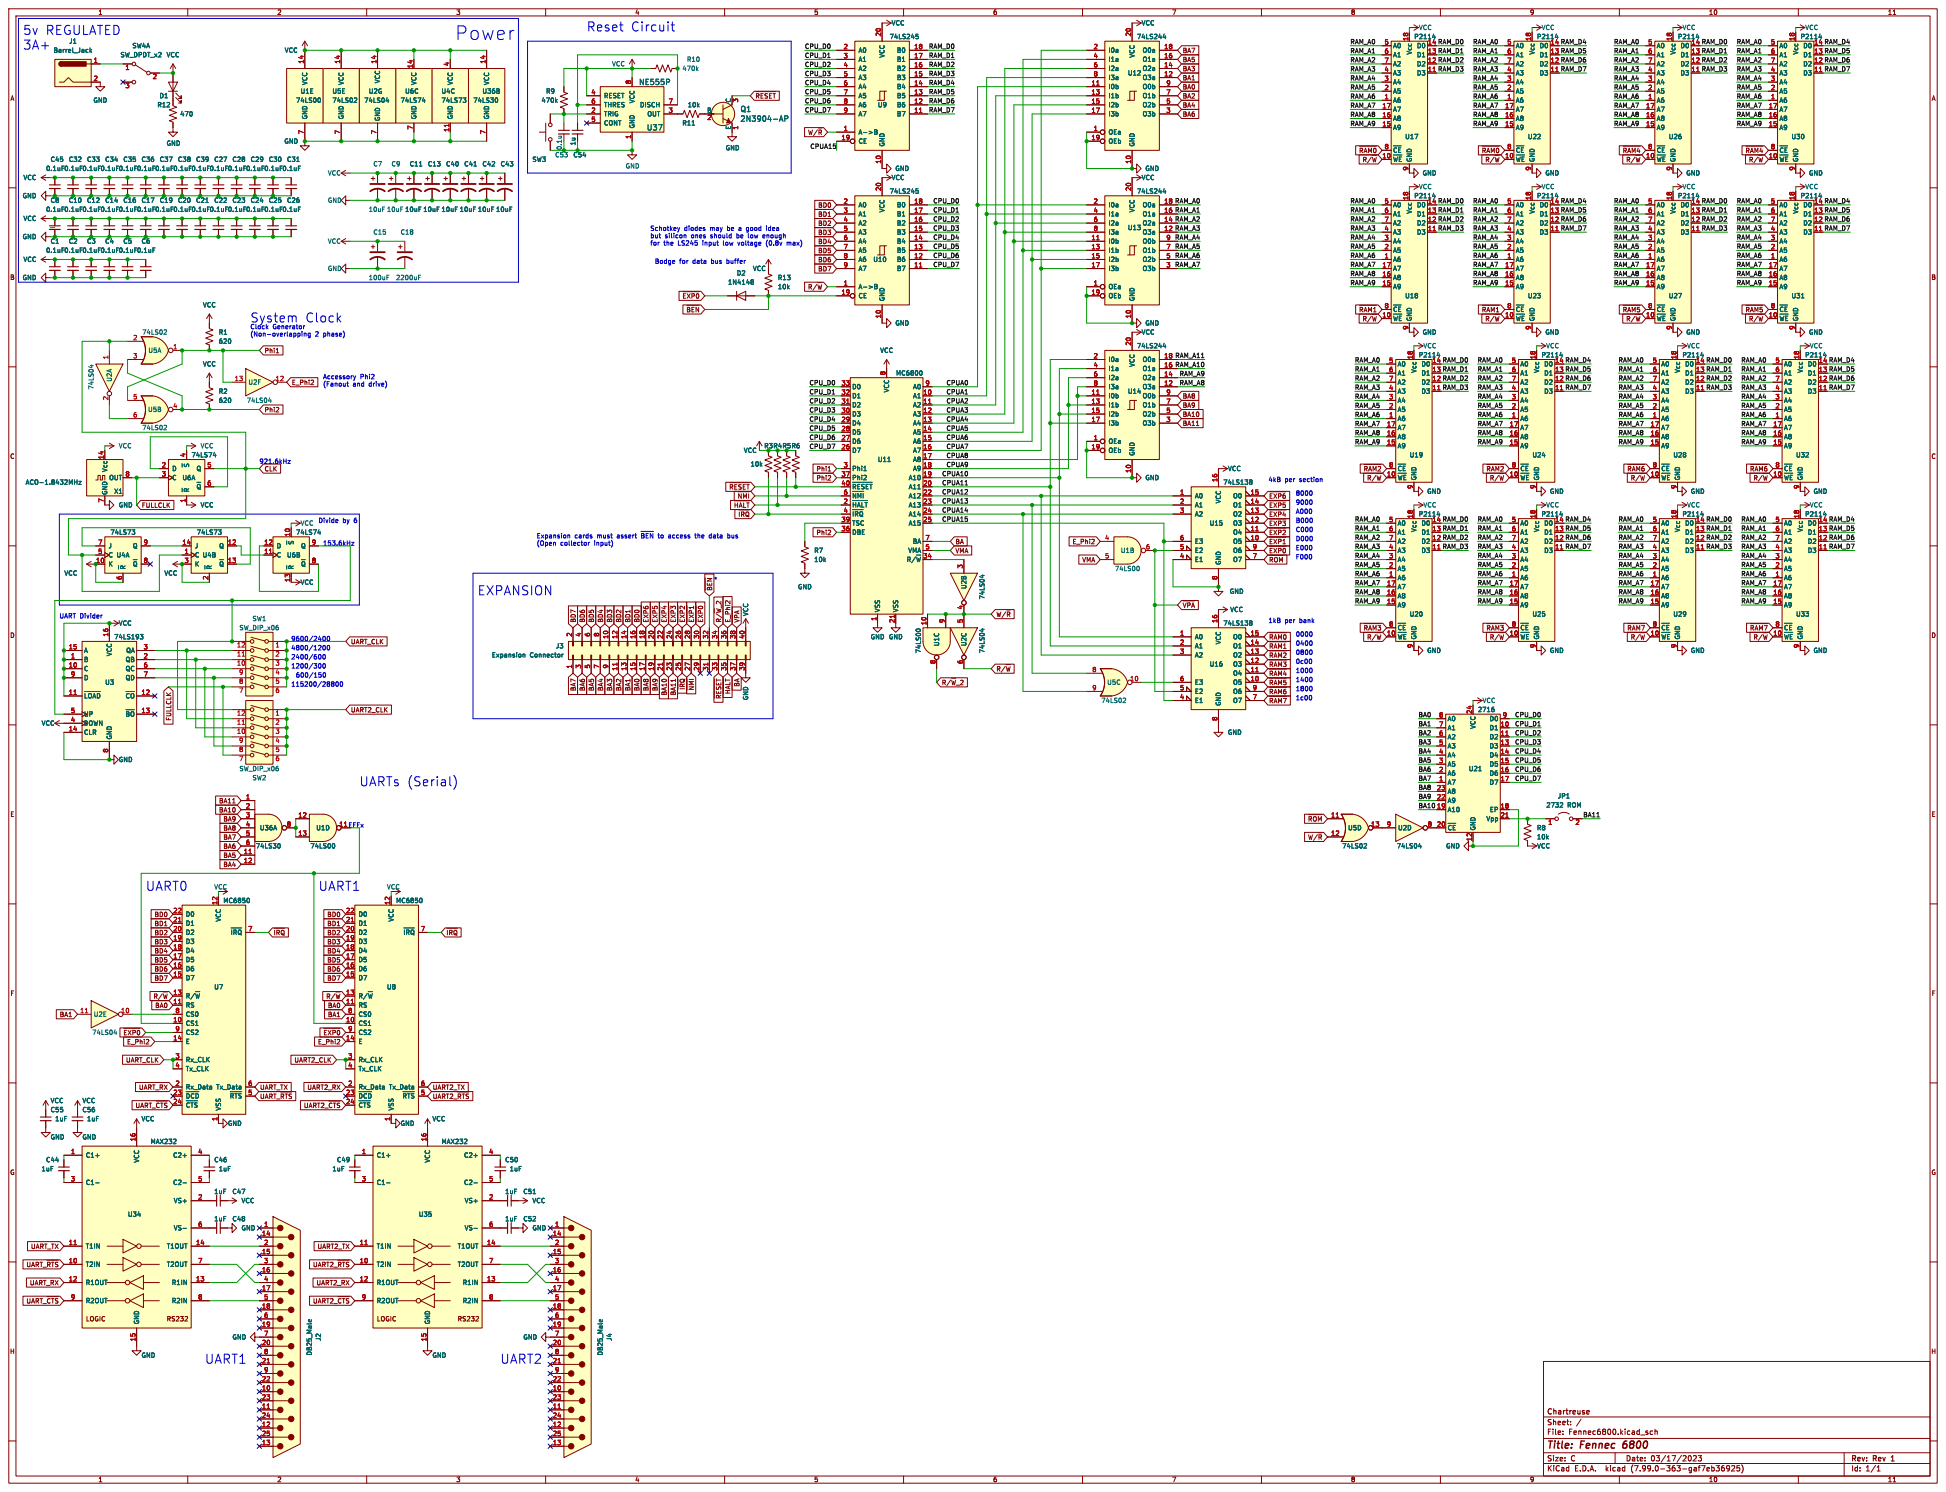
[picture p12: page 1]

4kB per section Bodge for data bus buffer 5v REGULATED

1 TRIG 2 OUT 3 RESET 4 CONT 5 THRES 6 DISCH VCC 7

Schotkey diodes may be a good idea
but silicon ones should be low enough
for the LS245 input low voltage (0.8v max)

1 A1 10 A2 11 A3 12 A4 13 A5 14 A6 15 A7 16 A8 17 A9 18 A10 19 ~{HALT} 2 A11 20 VSS 21 A12 22 A13 23 A14 24 A15 25 D7 26 D6 27 D5 28 D4 29 Phi1 3 D3 30 D2 31 D1 32 D0 33 R/~{W}34 DBE 36 Phi2 37 TSC 39 ~{IRQ} 4 ~{RESET} 40 VMA 5 ~{NMI} 6 BA 7 VCC

0800 Expansion cards must assert ~{BEN}to access the data bus

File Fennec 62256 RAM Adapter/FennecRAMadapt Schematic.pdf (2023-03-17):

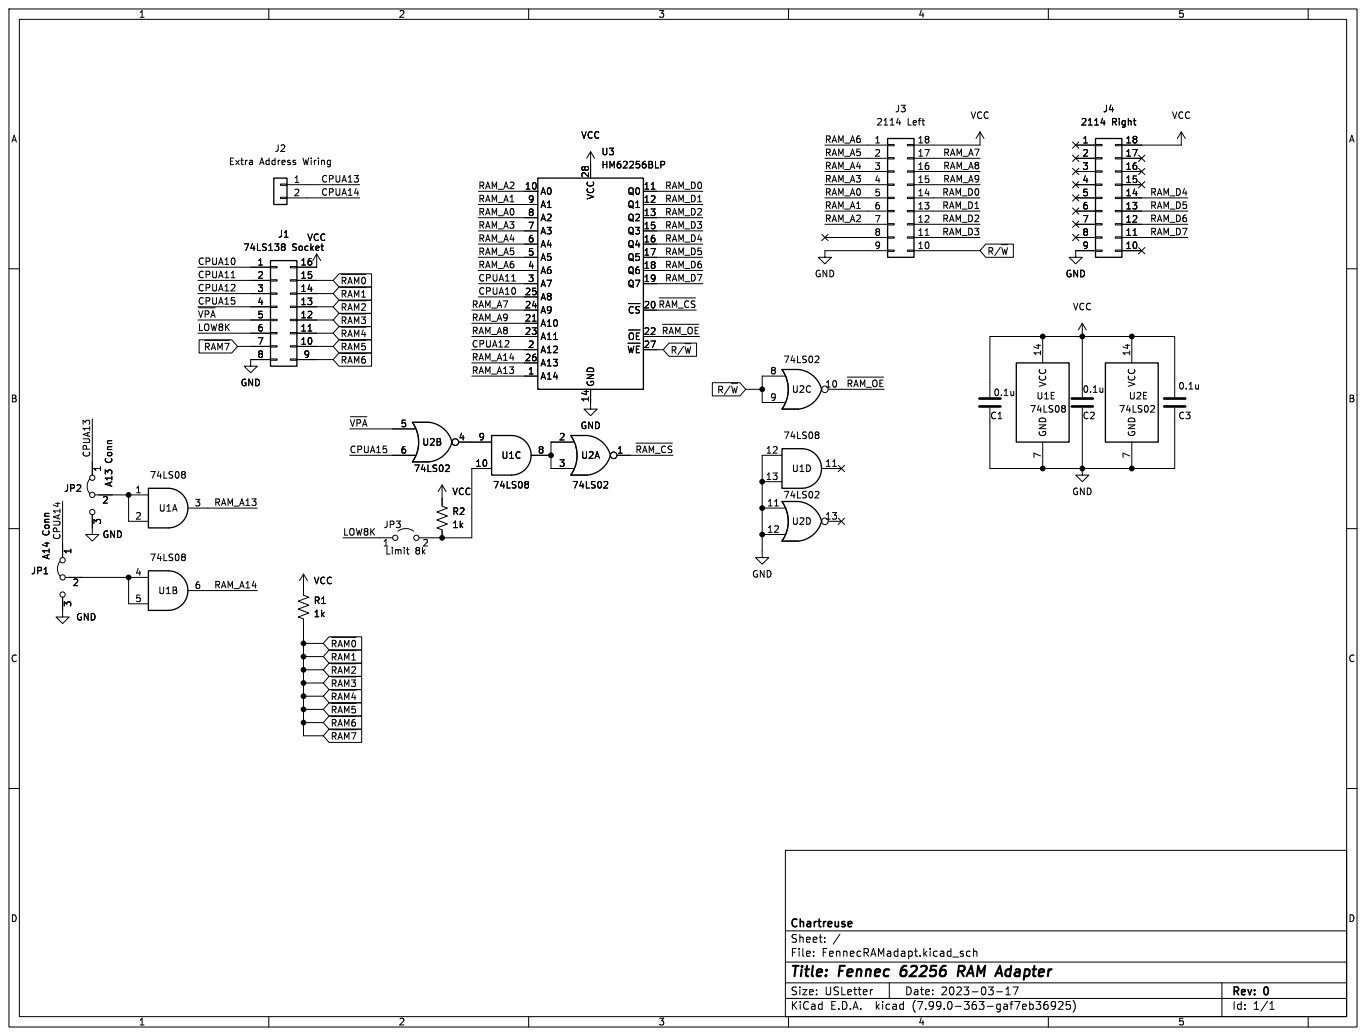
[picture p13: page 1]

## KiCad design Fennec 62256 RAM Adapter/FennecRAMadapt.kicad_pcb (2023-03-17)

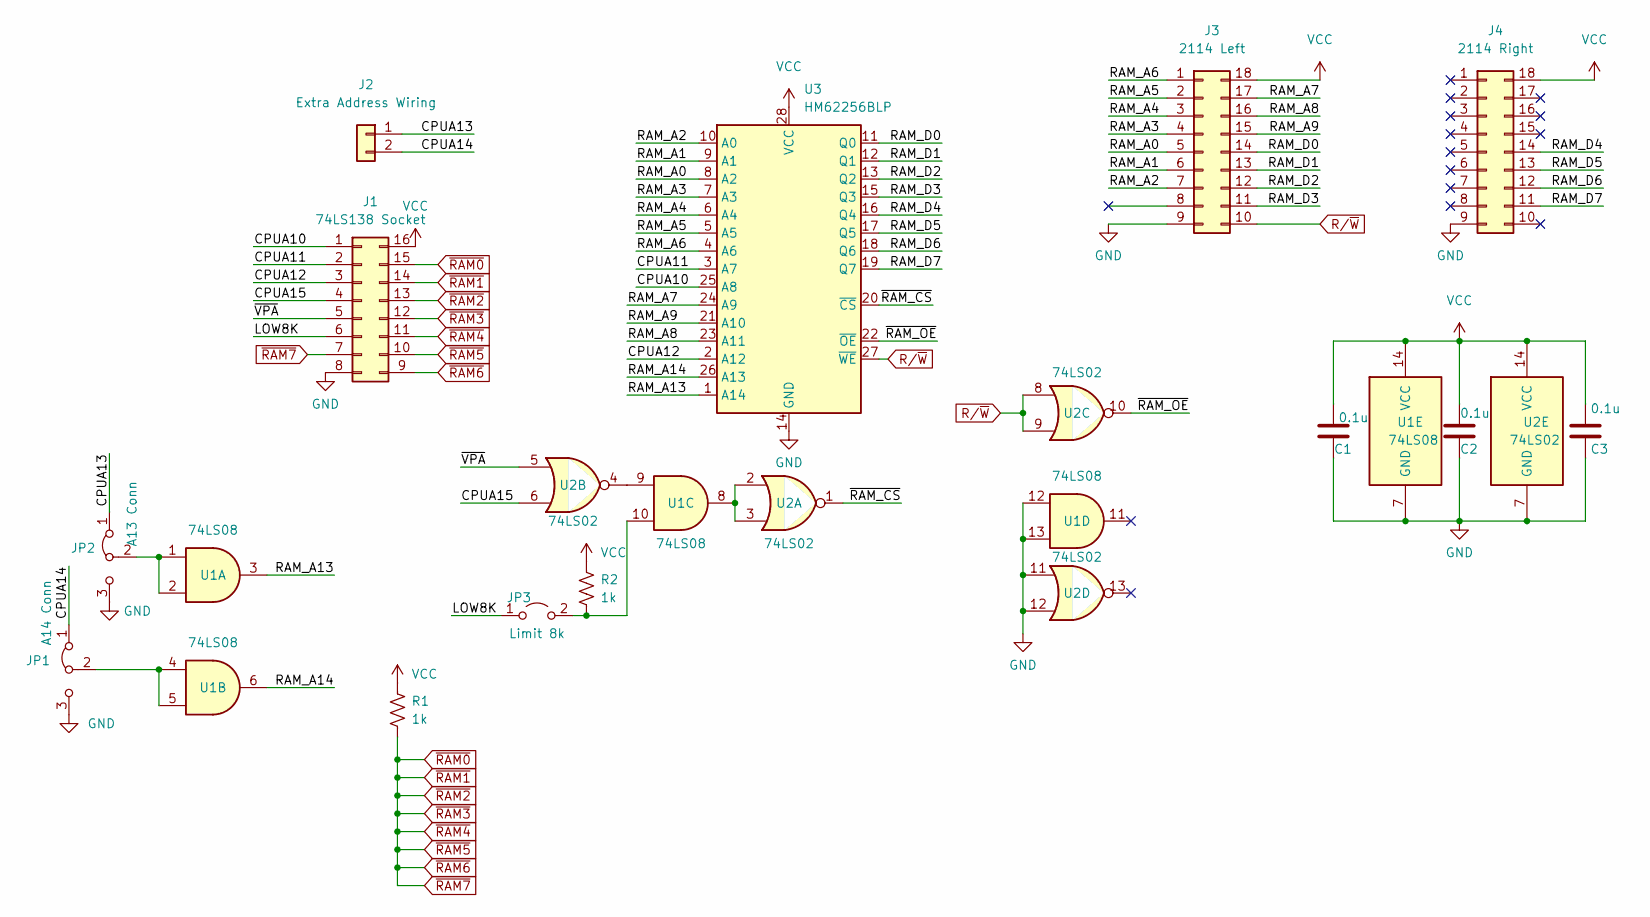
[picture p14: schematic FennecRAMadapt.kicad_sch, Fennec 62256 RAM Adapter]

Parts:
C1, C2, C3: 0.1u; C_Disc_D3.0mm_W1.6mm_P2.50mm
J1: 74LS138 Socket; DIP-16 Copper Ref Pin 1 Mark
J2: Extra Address Wiring; PinHeader_1x02_P2.54mm_Vertical
J3: 2114 Left; DIP-18 Copper Ref Pin 1 Mark
J4: 2114 Right; DIP-18 Copper Ref Pin 1 Mark
JP1: A14 Conn; PinHeader_1x03_P2.54mm_Vertical
JP2: A13 Conn; PinHeader_1x03_P2.54mm_Vertical
JP3: Limit 8k; PinHeader_1x02_P2.54mm_Vertical
R1, R2: 1k; R_Axial_DIN0207_L6.3mm_D2.5mm_P10.16mm_Horizontal
U1: 74LS08; DIP-14 Copper Ref Pin 1 Mark
U2: 74LS02; DIP-14 Copper Ref Pin 1 Mark
U3: HM62256BLP; DIP-28 Copper Ref Pin 1

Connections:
/CPUA10: J1.1, U3.25 (A8)
/CPUA11: J1.2, U3.3 (A7)
/CPUA12: J1.3, U3.2 (A12)
/CPUA13: J2.1, JP2.1 (A)
/CPUA14: J2.2, JP1.1 (A)
/CPUA15: J1.4, U2.6
/LOW8K: J1.6, JP3.1 (A); also elsewhere on the board
/RAM_A0: J3.5, U3.8 (A2)
/RAM_A1: J3.6, U3.9 (A1)
/RAM_A2: J3.7, U3.10 (A0)
/RAM_A3: J3.4, U3.7 (A3)
/RAM_A4: J3.3, U3.6 (A4)
/RAM_A5: J3.2, U3.5 (A5)
/RAM_A6: J3.1, U3.4 (A6)
/RAM_A7: J3.17, U3.24 (A9)
/RAM_A8: J3.16, U3.23 (A11)
/RAM_A9: J3.15, U3.21 (A10)
/RAM_A13: U1.3, U3.1 (A14)
/RAM_A14: U1.6, U3.26 (A13)
/RAM_D0: J3.14, U3.11 (Q0)
/RAM_D1: J3.13, U3.12 (Q1)
/RAM_D2: J3.12, U3.13 (Q2)
/RAM_D3: J3.11, U3.15 (Q3)
/RAM_D4: J4.14, U3.16 (Q4)
/RAM_D5: J4.13, U3.17 (Q5)
/RAM_D6: J4.12, U3.18 (Q6)
/RAM_D7: J4.11, U3.19 (Q7)
/~RAM_CS: U2.1, U3.20 (~CS)
/~RAM_OE: U2.10, U3.22 (~OE)
/~VPA: J1.5, U2.5
GND: C1.2, C2.2, C3.2, J1.8, J3.9, J4.9, JP1.3 (B), JP2.3 (B), U1.7 (GND), U1.12, U1.13, U2.7 (GND), U2.11, U2.12, U3.14 (GND)
unnamed: JP1.2 (C), U1.4, U1.5
unnamed: JP2.2 (C), U1.1, U1.2
unnamed 33: JP3.2 (B), R2.2, U1.10; also elsewhere on the board
unnamed: U1.8, U2.2, U2.3
unnamed: U1.9, U2.4
R/~W: J3.10, U2.8, U2.9, U3.27 (~WE)
VCC: C1.1, C2.1, C3.1, J1.16, J3.18, J4.18, R1.1, R2.1, U1.14 (VCC), U2.14 (VCC), U3.28 (VCC)
~RAM7: J1.7, J1.9, J1.10, J1.11, J1.12, J1.13, J1.14, J1.15, R1.2

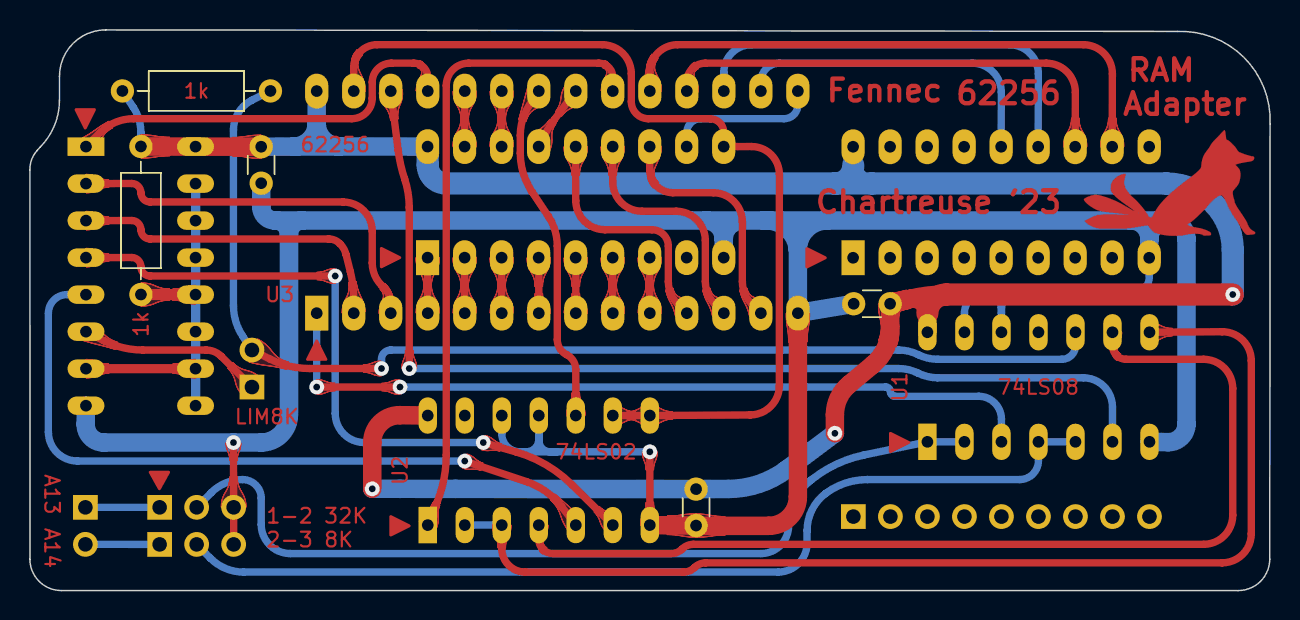
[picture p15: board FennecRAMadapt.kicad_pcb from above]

Board: 2 copper layers, 85.1 x 38.5 mm, 16 parts (0 on the bottom side), 39 nets.

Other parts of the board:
LIM8K: Limit 8k; PinHeader_1x02_P2.54mm_Vertical
P1: Mounting Support DNC; PinHeader_1x09_P2.54mm_Vertical

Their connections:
/LOW8K: LIM8K.1 (A); also elsewhere on the board
unnamed 33: LIM8K.2 (B); also elsewhere on the board

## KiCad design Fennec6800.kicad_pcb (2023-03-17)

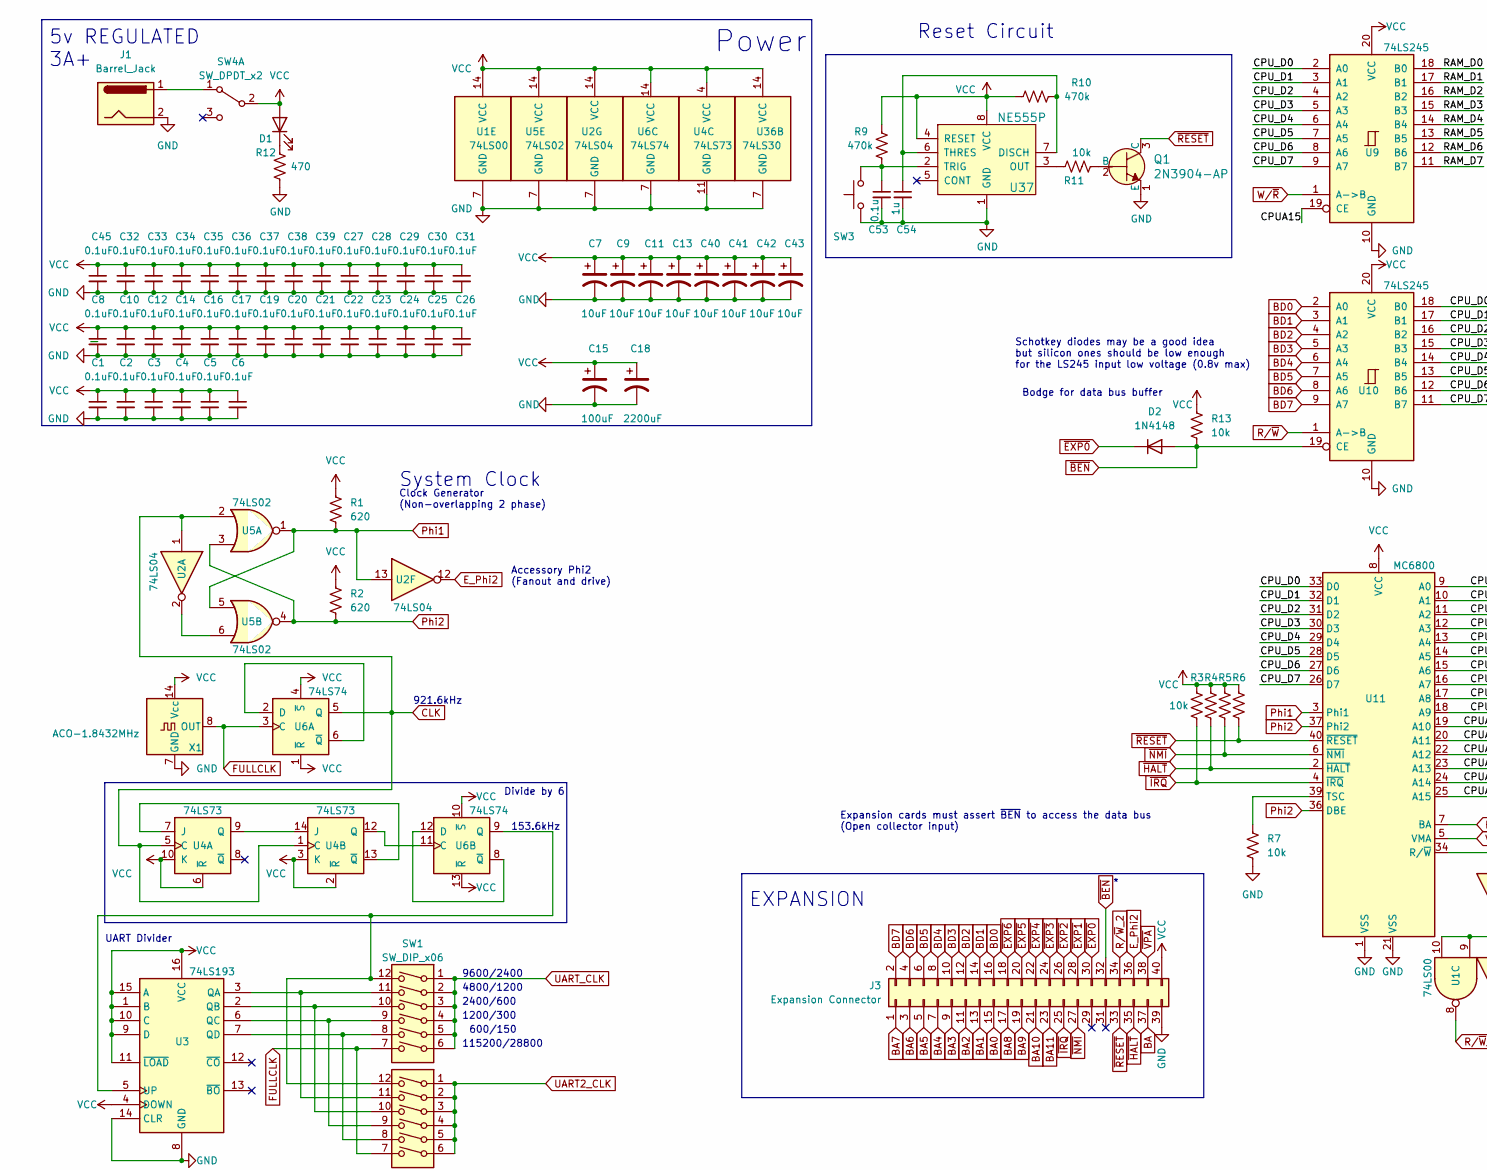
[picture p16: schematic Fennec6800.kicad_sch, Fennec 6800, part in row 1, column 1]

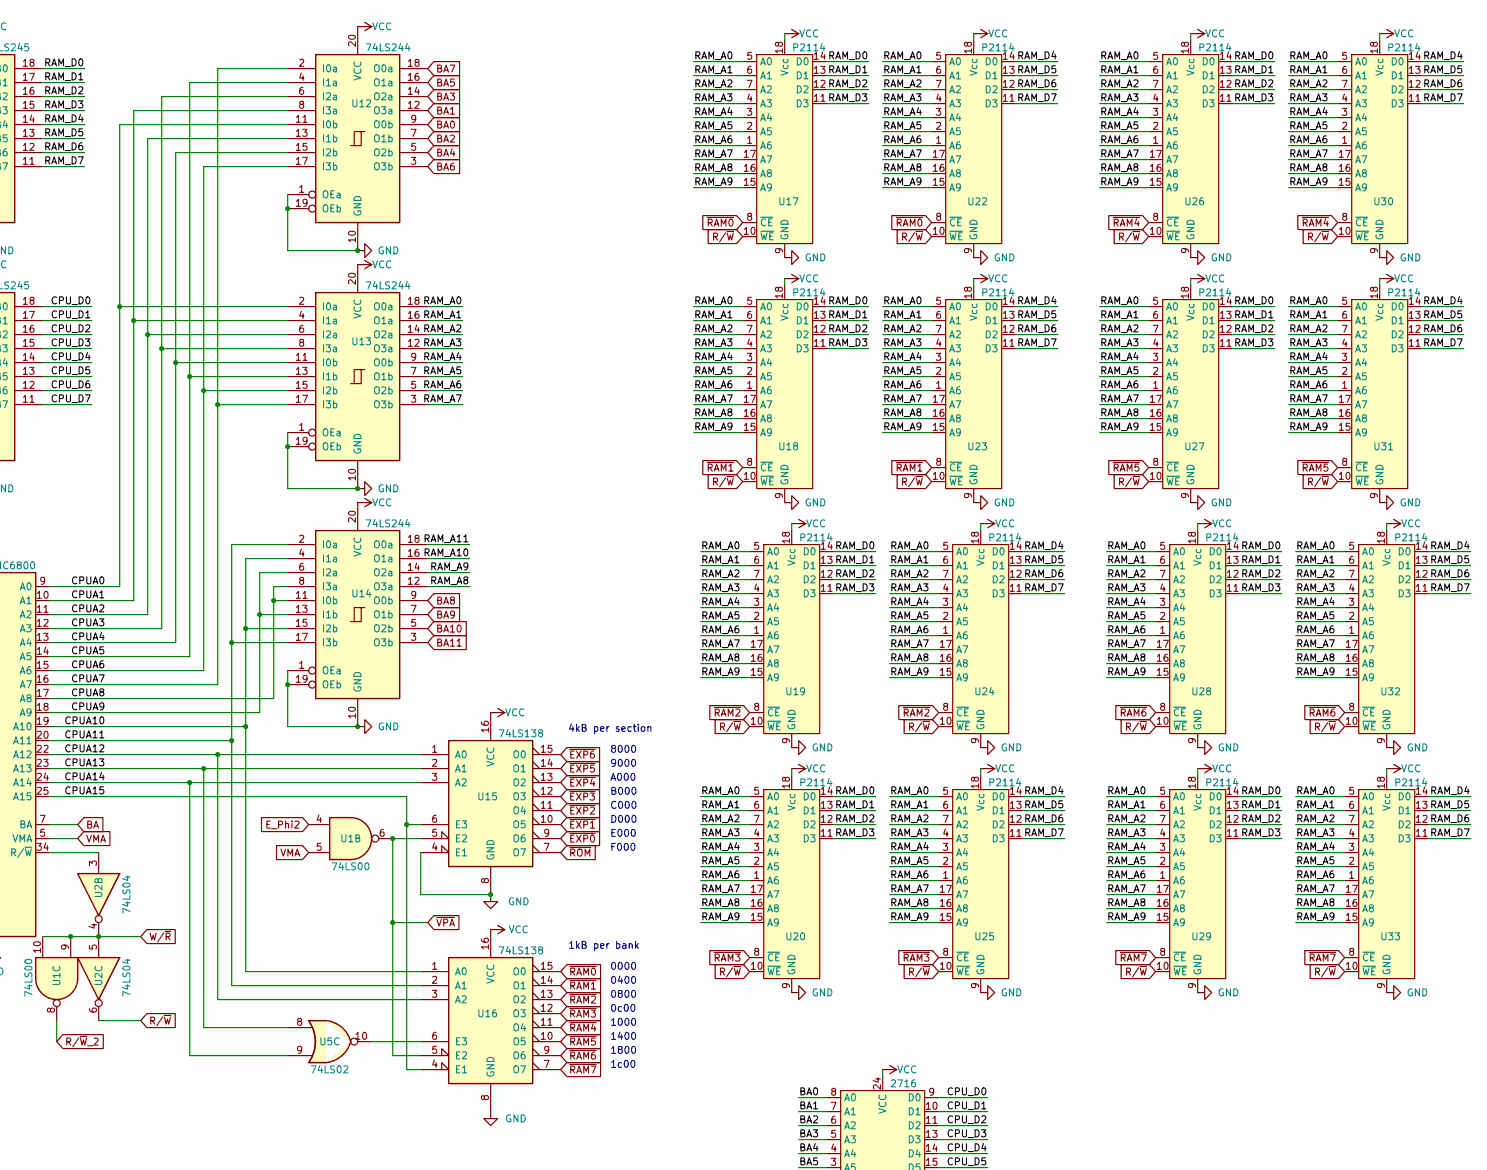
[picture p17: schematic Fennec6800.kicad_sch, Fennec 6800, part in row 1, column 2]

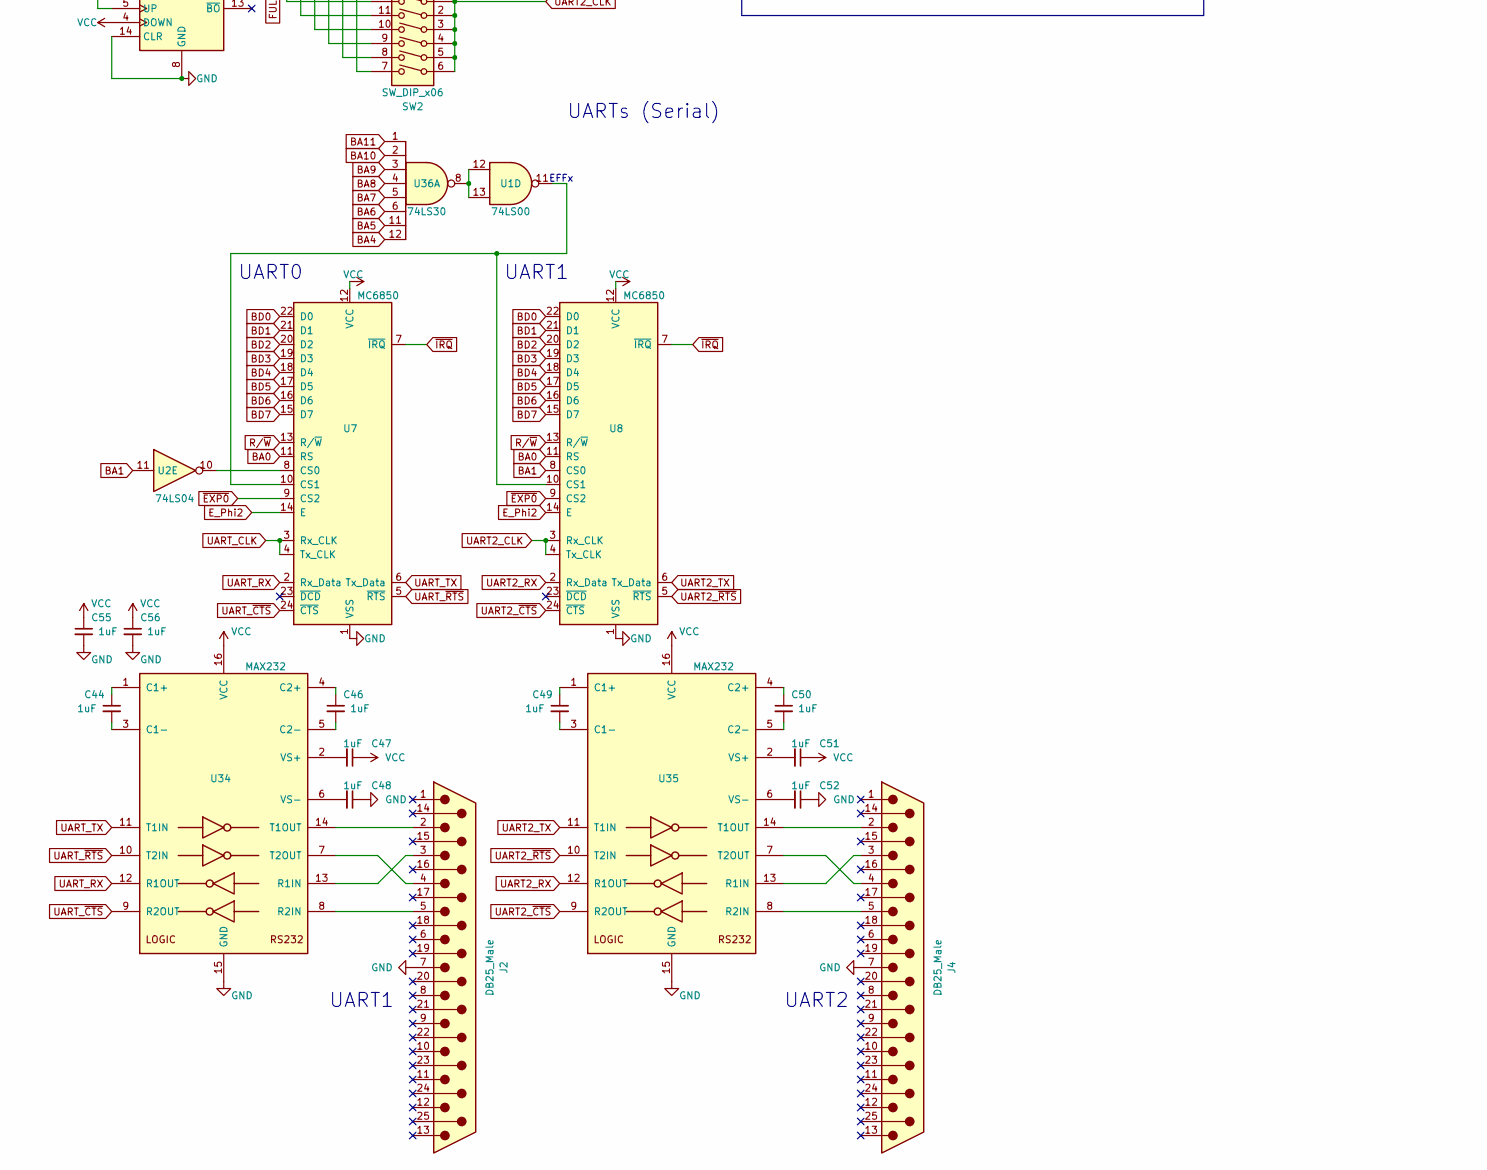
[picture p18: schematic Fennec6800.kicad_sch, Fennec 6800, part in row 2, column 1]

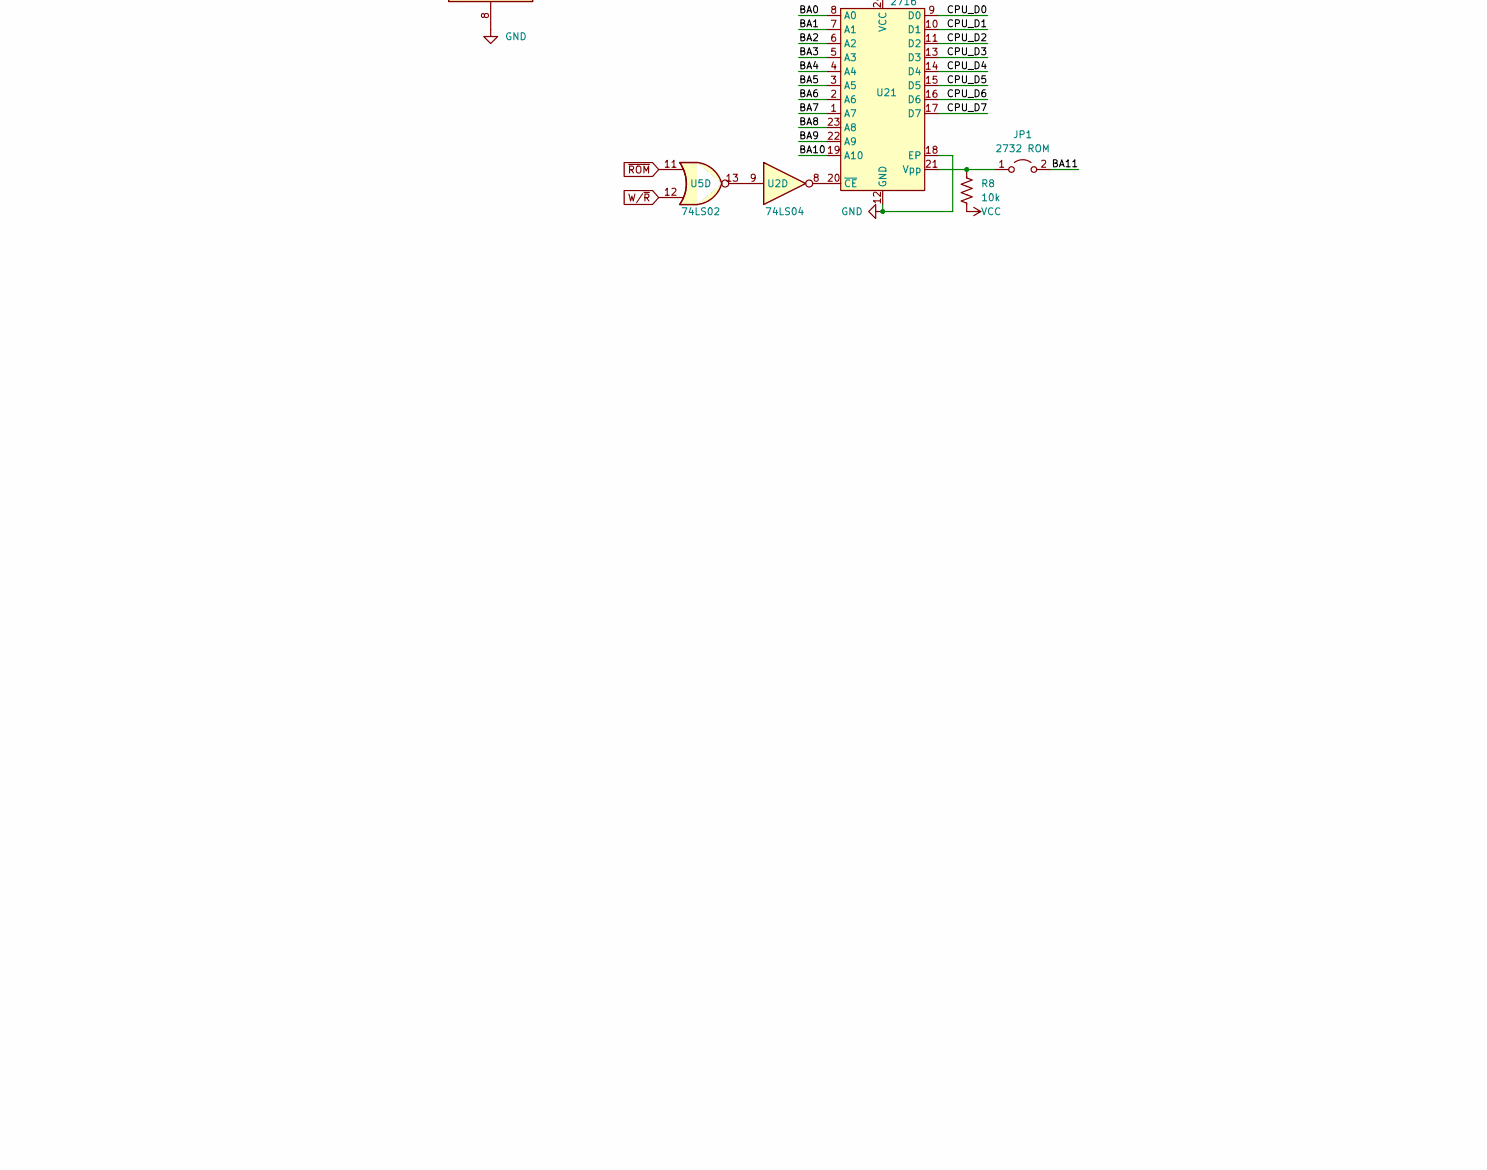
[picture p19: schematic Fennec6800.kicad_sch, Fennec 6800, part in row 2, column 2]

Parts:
C1, C2, C3, C4, C5, C6, C8, C10, C12, C14, C16, C17, C19, C20, C21, C22, C23, C24, C25, C26, C27, C28, C29, C30, C31, C32, C33, C34, C35, C36, C37, C38, C39, C45: 0.1uF; C_Disc_D3.8mm_W2.6mm_P2.50mm
C7, C9, C11, C13, C40, C41, C42, C43: 10uF; CP_Radial_Tantal_D4.5mm_P2.50mm
C15: 100uF; CP_Radial_D6.3mm_P2.50mm
C18: 2200uF; CP_Radial_D12.5mm_P5.00mm
C44, C46, C47, C48, C49, C50, C51, C52, C55, C56: 1uF; C_Disc_D3.8mm_W2.6mm_P2.50mm
C53: 0.1u; C_Rect_L4.0mm_W2.5mm_P2.50mm
C54: 1u; C_Rect_L4.0mm_W2.5mm_P2.50mm
D1: LED; LED_D5.0mm
D2: 1N4148
J1: Barrel_Jack; BarrelJack_Horizontal
J2, J4: DB25_Male; DSUB-25_Male_Horizontal_P2.77x2.84mm_EdgePinOffset7.70mm_Ho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
J3: Expansion Connector; PinHeader_2x20_P2.54mm_Vertical
JP1: 2732 ROM; PinHeader_1x02_P2.54mm_Vertical
Q1: 2N3904-AP; TO-92; MPN 2N3904-AP; Digi-Key_PN 2N3904-APCT-ND
R1, R2: 620; R_Axial_DIN0207_L6.3mm_D2.5mm_P10.16mm_Horizontal
R3, R4, R5, R6, R7, R8, R13: 10k; R_Axial_DIN0207_L6.3mm_D2.5mm_P10.16mm_Horizontal
R9, R10: 470k; R_Axial_DIN0207_L6.3mm_D2.5mm_P2.54mm_Vertical
R11: 10k; R_Axial_DIN0207_L6.3mm_D2.5mm_P2.54mm_Vertical
R12: 470; R_Axial_DIN0207_L6.3mm_D2.5mm_P10.16mm_Horizontal
SW1, SW2: SW_DIP_x06; SW_DIP_SPSTx06_Slide_9.78x17.42mm_W7.62mm_P2.54mm
SW3: SW_Push; SW_PUSH_6mm
SW4: SW_DPDT_x2; VerticalToggle_ESWITCH_100SP1T2B4M7QE
U1: 74LS00; DIP-14_W7.62mm_Socket_LongPads
U2: 74LS04; DIP-14_W7.62mm_Socket_LongPads
U3: 74LS193; DIP-16_W7.62mm_Socket_LongPads
U4: 74LS73; DIP-14_W7.62mm_Socket_LongPads
U5: 74LS02; DIP-14_W7.62mm_Socket_LongPads
U6: 74LS74; DIP-14_W7.62mm_Socket_LongPads
U7, U8: MC6850; DIP-24_W15.24mm_Socket_LongPads
U9, U10: 74LS245; DIP-20_W7.62mm_Socket_LongPads
U11: MC6800; DIP-40_W15.24mm_Socket_LongPads
U12, U13, U14: 74LS244; DIP-20_W7.62mm_Socket_LongPads
U15, U16: 74LS138; DIP-16_W7.62mm_Socket_LongPads
U17, U18, U19, U20, U22, U23, U24, U25, U26, U27, U28, U29, U30, U31, U32, U33: P2114; DIP-18_W7.62mm_Socket_LongPads
U21: 2716; DIP-24_W15.24mm_Socket_LongPads
U34, U35: MAX232; DIP-16_W7.62mm_Socket_LongPads
U36: 74LS30; DIP-14_W7.62mm_Socket_LongPads
U37: NE555P; DIP-8_W7.62mm_Socket_LongPads; MPN NE555P; Digi-Key_PN 296-1411-5-ND
X1: ACO-1.8432MHz; Oscillator_DIP-14

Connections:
/CPUA0: U11.9 (A0), U12.11 (I0b), U13.2 (I0a)
/CPUA1: U11.10 (A1), U12.8 (I3a), U13.4 (I1a)
/CPUA2: U11.11 (A2), U12.13 (I1b), U13.6 (I2a)
/CPUA3: U11.12 (A3), U12.6 (I2a), U13.8 (I3a)
/CPUA4: U11.13 (A4), U12.15 (I2b), U13.11 (I0b)
/CPUA5: U11.14 (A5), U12.4 (I1a), U13.13 (I1b)
/CPUA6: U11.15 (A6), U12.17 (I3b), U13.15 (I2b)
/CPUA7: U11.16 (A7), U12.2 (I0a), U13.17 (I3b)
/CPUA8: U11.17 (A8), U14.8 (I3a), U14.11 (I0b)
/CPUA9: U11.18 (A9), U14.6 (I2a), U14.13 (I1b)
/CPUA10: U11.19 (A10), U14.4 (I1a), U14.15 (I2b), U16.1 (A0)
/CPUA11: U11.20 (A11), U14.2 (I0a), U14.17 (I3b), U16.2 (A1)
/CPUA12: U11.22 (A12), U15.1 (A0), U16.3 (A2)
/CPUA13: U5.8, U11.23 (A13), U15.2 (A1)
/CPUA14: U5.9, U11.24 (A14), U15.3 (A2)
/CPU_D0: U9.2 (A0), U10.18 (B0), U11.33 (D0), U21.9 (D0)
/CPU_D1: U9.3 (A1), U10.17 (B1), U11.32 (D1), U21.10 (D1)
/CPU_D2: U9.4 (A2), U10.16 (B2), U11.31 (D2), U21.11 (D2)
/CPU_D3: U9.5 (A3), U10.15 (B3), U11.30 (D3), U21.13 (D3)
/CPU_D4: U9.6 (A4), U10.14 (B4), U11.29 (D4), U21.14 (D4)
/CPU_D5: U9.7 (A5), U10.13 (B5), U11.28 (D5), U21.15 (D5)
/CPU_D6: U9.8 (A6), U10.12 (B6), U11.27 (D6), U21.16 (D6)
/CPU_D7: U9.9 (A7), U10.11 (B7), U11.26 (D7), U21.17 (D7)
/RAM_A0: U13.18 (O0a), U17.5 (A0), U18.5 (A0), U19.5 (A0), U20.5 (A0), U22.5 (A0), U23.5 (A0), U24.5 (A0), U25.5 (A0), U26.5 (A0), U27.5 (A0), U28.5 (A0), U29.5 (A0), U30.5 (A0), U31.5 (A0), U32.5 (A0), U33.5 (A0)
/RAM_A1: U13.16 (O1a), U17.6 (A1), U18.6 (A1), U19.6 (A1), U20.6 (A1), U22.6 (A1), U23.6 (A1), U24.6 (A1), U25.6 (A1), U26.6 (A1), U27.6 (A1), U28.6 (A1), U29.6 (A1), U30.6 (A1), U31.6 (A1), U32.6 (A1), U33.6 (A1)
/RAM_A2: U13.14 (O2a), U17.7 (A2), U18.7 (A2), U19.7 (A2), U20.7 (A2), U22.7 (A2), U23.7 (A2), U24.7 (A2), U25.7 (A2), U26.7 (A2), U27.7 (A2), U28.7 (A2), U29.7 (A2), U30.7 (A2), U31.7 (A2), U32.7 (A2), U33.7 (A2)
/RAM_A3: U13.12 (O3a), U17.4 (A3), U18.4 (A3), U19.4 (A3), U20.4 (A3), U22.4 (A3), U23.4 (A3), U24.4 (A3), U25.4 (A3), U26.4 (A3), U27.4 (A3), U28.4 (A3), U29.4 (A3), U30.4 (A3), U31.4 (A3), U32.4 (A3), U33.4 (A3)
/RAM_A4: U13.9 (O0b), U17.3 (A4), U18.3 (A4), U19.3 (A4), U20.3 (A4), U22.3 (A4), U23.3 (A4), U24.3 (A4), U25.3 (A4), U26.3 (A4), U27.3 (A4), U28.3 (A4), U29.3 (A4), U30.3 (A4), U31.3 (A4), U32.3 (A4), U33.3 (A4)
/RAM_A5: U13.7 (O1b), U17.2 (A5), U18.2 (A5), U19.2 (A5), U20.2 (A5), U22.2 (A5), U23.2 (A5), U24.2 (A5), U25.2 (A5), U26.2 (A5), U27.2 (A5), U28.2 (A5), U29.2 (A5), U30.2 (A5), U31.2 (A5), U32.2 (A5), U33.2 (A5)
/RAM_A6: U13.5 (O2b), U17.1 (A6), U18.1 (A6), U19.1 (A6), U20.1 (A6), U22.1 (A6), U23.1 (A6), U24.1 (A6), U25.1 (A6), U26.1 (A6), U27.1 (A6), U28.1 (A6), U29.1 (A6), U30.1 (A6), U31.1 (A6), U32.1 (A6), U33.1 (A6)
/RAM_A7: U13.3 (O3b), U17.17 (A7), U18.17 (A7), U19.17 (A7), U20.17 (A7), U22.17 (A7), U23.17 (A7), U24.17 (A7), U25.17 (A7), U26.17 (A7), U27.17 (A7), U28.17 (A7), U29.17 (A7), U30.17 (A7), U31.17 (A7), U32.17 (A7), U33.17 (A7)
/RAM_A8: U14.12 (O3a), U17.16 (A8), U18.16 (A8), U19.16 (A8), U20.16 (A8), U22.16 (A8), U23.16 (A8), U24.16 (A8), U25.16 (A8), U26.16 (A8), U27.16 (A8), U28.16 (A8), U29.16 (A8), U30.16 (A8), U31.16 (A8), U32.16 (A8), U33.16 (A8)
/RAM_A9: U14.14 (O2a), U17.15 (A9), U18.15 (A9), U19.15 (A9), U20.15 (A9), U22.15 (A9), U23.15 (A9), U24.15 (A9), U25.15 (A9), U26.15 (A9), U27.15 (A9), U28.15 (A9), U29.15 (A9), U30.15 (A9), U31.15 (A9), U32.15 (A9), U33.15 (A9)
/RAM_A10: U14.16 (O1a)
/RAM_A11: U14.18 (O0a)
/RAM_D0: U9.18 (B0), U17.14 (D0), U18.14 (D0), U19.14 (D0), U20.14 (D0), U26.14 (D0), U27.14 (D0), U28.14 (D0), U29.14 (D0)
/RAM_D1: U9.17 (B1), U17.13 (D1), U18.13 (D1), U19.13 (D1), U20.13 (D1), U26.13 (D1), U27.13 (D1), U28.13 (D1), U29.13 (D1)
/RAM_D2: U9.16 (B2), U17.12 (D2), U18.12 (D2), U19.12 (D2), U20.12 (D2), U26.12 (D2), U27.12 (D2), U28.12 (D2), U29.12 (D2)
/RAM_D3: U9.15 (B3), U17.11 (D3), U18.11 (D3), U19.11 (D3), U20.11 (D3), U26.11 (D3), U27.11 (D3), U28.11 (D3), U29.11 (D3)
/RAM_D4: U9.14 (B4), U22.14 (D0), U23.14 (D0), U24.14 (D0), U25.14 (D0), U30.14 (D0), U31.14 (D0), U32.14 (D0), U33.14 (D0)
/RAM_D5: U9.13 (B5), U22.13 (D1), U23.13 (D1), U24.13 (D1), U25.13 (D1), U30.13 (D1), U31.13 (D1), U32.13 (D1), U33.13 (D1)
/RAM_D6: U9.12 (B6), U22.12 (D2), U23.12 (D2), U24.12 (D2), U25.12 (D2), U30.12 (D2), U31.12 (D2), U32.12 (D2), U33.12 (D2)
/RAM_D7: U9.11 (B7), U22.11 (D3), U23.11 (D3), U24.11 (D3), U25.11 (D3), U30.11 (D3), U31.11 (D3), U32.11 (D3), U33.11 (D3)
BA: J3.37, U11.7 (BA)
BA0: J3.15, U7.11 (RS), U8.11 (RS), U12.9 (O0b), U21.8 (A0)
BA1: J3.13, U2.11, U8.8 (CS0), U12.12 (O3a), U21.7 (A1)
BA2: J3.11, U12.7 (O1b), U21.6 (A2)
BA3: J3.9, U12.14 (O2a), U21.5 (A3)
BA4: J3.7, U12.5 (O2b), U21.4 (A4), U36.12
BA5: J3.5, U12.16 (O1a), U21.3 (A5), U36.11
BA6: J3.3, U12.3 (O3b), U21.2 (A6), U36.6
BA7: J3.1, U12.18 (O0a), U21.1 (A7), U36.5
BA8: J3.17, U14.9 (O0b), U21.23 (A8), U36.4
BA9: J3.19, U14.7 (O1b), U21.22 (A9), U36.3
BA10: J3.21, U14.5 (O2b), U21.19 (A10), U36.2
BA11: J3.23, JP1.2 (B), U14.3 (O3b), U36.1
BD0: J3.16, U7.22 (D0), U8.22 (D0), U10.2 (A0)
BD1: J3.14, U7.21 (D1), U8.21 (D1), U10.3 (A1)
BD2: J3.12, U7.20 (D2), U8.20 (D2), U10.4 (A2)
BD3: J3.10, U7.19 (D3), U8.19 (D3), U10.5 (A3)
BD4: J3.8, U7.18 (D4), U8.18 (D4), U10.6 (A4)
BD5: J3.6, U7.17 (D5), U8.17 (D5), U10.7 (A5)
BD6: J3.4, U7.16 (D6), U8.16 (D6), U10.8 (A6)
BD7: J3.2, U7.15 (D7), U8.15 (D7), U10.9 (A7)
unnamed: C44.1, U34.1 (C1+)
unnamed: C44.2, U34.3 (C1-)
unnamed: C46.1, U34.4 (C2+)
unnamed: C46.2, U34.5 (C2-)
unnamed: C47.2, U34.2 (VS+)
unnamed: C48.2, U34.6 (VS-)
unnamed: C49.1, U35.1 (C1+)
unnamed: C49.2, U35.3 (C1-)
unnamed: C50.1, U35.4 (C2+)
unnamed: C50.2, U35.5 (C2-)
unnamed: C51.2, U35.2 (VS+)
unnamed: C52.2, U35.6 (VS-)
unnamed: C53.1, R9.2, SW3.2, U37.2 (TRIG)
unnamed: C54.1, R10.1, U37.6 (THRES), U37.7 (DISCH)
unnamed: J1.1, SW4.1 (A)
unnamed: J2.2, U34.14 (T1OUT)
unnamed: J2.3, U34.13 (R1IN)
unnamed: J2.4, U34.7 (T2OUT)
unnamed: J2.5, U34.8 (R2IN)
unnamed: J4.2, U35.14 (T1OUT)
unnamed: J4.3, U35.13 (R1IN)
unnamed: J4.4, U35.7 (T2OUT)
unnamed: J4.5, U35.8 (R2IN)
unnamed: JP1.1 (A), R8.2, U21.21 (Vpp)
unnamed: Q1.2 (B), R11.2
unnamed: R7.1, U11.39 (TSC)
unnamed: R11.1, U37.3 (OUT)
unnamed: SW1.8, SW2.8, U3.7 (QD)
unnamed: SW1.9, SW2.9, U3.6 (QC)
unnamed: SW1.10, SW2.10, U3.2 (QB)
unnamed: SW1.11, SW2.11, U3.3 (QA)
unnamed: SW1.12, SW2.12, U3.5 (UP), U6.9 (Q)
unnamed: U1.11, U7.10 (CS1), U8.10 (CS1)
unnamed: U1.12, U1.13, U36.8
unnamed: U2.2, U5.6
unnamed: U2.8, U21.20 (~CE)
unnamed: U2.9, U5.13
unnamed: U2.10, U7.8 (CS0)
unnamed: U4.12 (Q), U6.11 (C)
unnamed: U4.7 (J), U4.13 (~Q)
unnamed: U4.9 (Q), U4.14 (J)
unnamed: U6.2 (D), U6.6 (~Q)
unnamed: U6.8 (~Q), U6.12 (D)
unnamed: U2.3, U11.34 (R/~W)
unnamed: U5.10, U16.6 (E3)
Phi1: R1.2, U2.13, U5.1, U5.5, U11.3 (Phi1)
Phi2: R2.2, U5.3, U5.4, U11.36 (DBE), U11.37 (Phi2)
R/~W: U2.6, U7.13 (R/~W), U8.13 (R/~W), U10.1 (A->B), U17.10 (~WE), U18.10 (~WE), U19.10 (~WE), U20.10 (~WE), U22.10 (~WE), U23.10 (~WE), U24.10 (~WE), U25.10 (~WE), U26.10 (~WE), U27.10 (~WE), U28.10 (~WE), U29.10 (~WE), U30.10 (~WE), U31.10 (~WE), U32.10 (~WE), U33.10 (~WE)
R/~W_2: J3.34, U1.8
UART2_CLK: SW2.1, SW2.2, SW2.3, SW2.4, SW2.5, SW2.6, U8.3 (Rx_CLK), U8.4 (Tx_CLK)
UART2_RX: U8.2 (Rx_Data), U35.12 (R1OUT)
UART2_TX: U8.6 (Tx_Data), U35.11 (T1IN)
UART2_~CTS: U8.24 (~CTS), U35.9 (R2OUT)
UART2_~RTS: U8.5 (~RTS), U35.10 (T2IN)
UART_CLK: SW1.1, SW1.2, SW1.3, SW1.4, SW1.5, SW1.6, U7.3 (Rx_CLK), U7.4 (Tx_CLK)
UART_RX: U7.2 (Rx_Data), U34.12 (R1OUT)
UART_TX: U7.6 (Tx_Data), U34.11 (T1IN)
UART_~CTS: U7.24 (~CTS), U34.9 (R2OUT)
UART_~RTS: U7.5 (~RTS), U34.10 (T2IN)
VMA: U1.5, U11.5 (VMA)
VPA: J3.38, U1.6, U15.5 (E2), U16.5 (E2)
W/~R: U1.9, U1.10, U2.4, U2.5, U5.12, U9.1 (A->B)
~EXP0: D2.1 (K), J3.30, U7.9 (CS2), U8.9 (CS2), U15.9 (O6)
~EXP1: J3.28, U15.10 (O5)
~EXP2: J3.26, U15.11 (O4)
~EXP3: J3.24, U15.12 (O3)
~EXP4: J3.22, U15.13 (O2)
~EXP5: J3.20, U15.14 (O1)
~EXP6: J3.18, U15.15 (O0)
~HALT: J3.35, R4.2, U11.2 (~HALT)
~IRQ: J3.25, R3.2, U7.7 (~IRQ), U8.7 (~IRQ), U11.4 (~IRQ)
~NMI: J3.27, R5.2, U11.6 (~NMI)
~RAM0: U16.15 (O0), U17.8 (~CE), U22.8 (~CE)
~RAM1: U16.14 (O1), U18.8 (~CE), U23.8 (~CE)
~RAM2: U16.13 (O2), U19.8 (~CE), U24.8 (~CE)
~RAM3: U16.12 (O3), U20.8 (~CE), U25.8 (~CE)
~RAM4: U16.11 (O4), U26.8 (~CE), U30.8 (~CE)
~RAM5: U16.10 (O5), U27.8 (~CE), U31.8 (~CE)
~RAM6: U16.9 (O6), U28.8 (~CE), U32.8 (~CE)
~RAM7: U16.7 (O7), U29.8 (~CE), U33.8 (~CE)
~RESET: J3.33, Q1.3 (C), R6.2, U11.40 (~RESET)
~ROM: U5.11, U15.7 (O7)

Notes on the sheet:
1200/300
9000
2400/600
Divide by 6
UART0
UARTs (Serial)
Expansion cards must assert ~{BEN} to access the data bus (Open collector input)
0800
Reset Circuit
4kB per section
C000
A000
1c00
UART1
8000
153.6kHz
Accessory Phi2 (Fanout and drive)
0c00
1800
1kB per bank
5v REGULATED 3A+
Bodge for data bus buffer
Schotkey diodes may be a good idea but silicon ones should be low enough for the LS245 input low voltage (0.8v max)
D000
E000
115200/28800
1400
UART Divider
921.6kHz
9600/2400
System Clock
EFFx
Power
600/150
0000
B000
EXPANSION
0400
Clock Generator (Non-overlapping 2 phase)
4800/1200

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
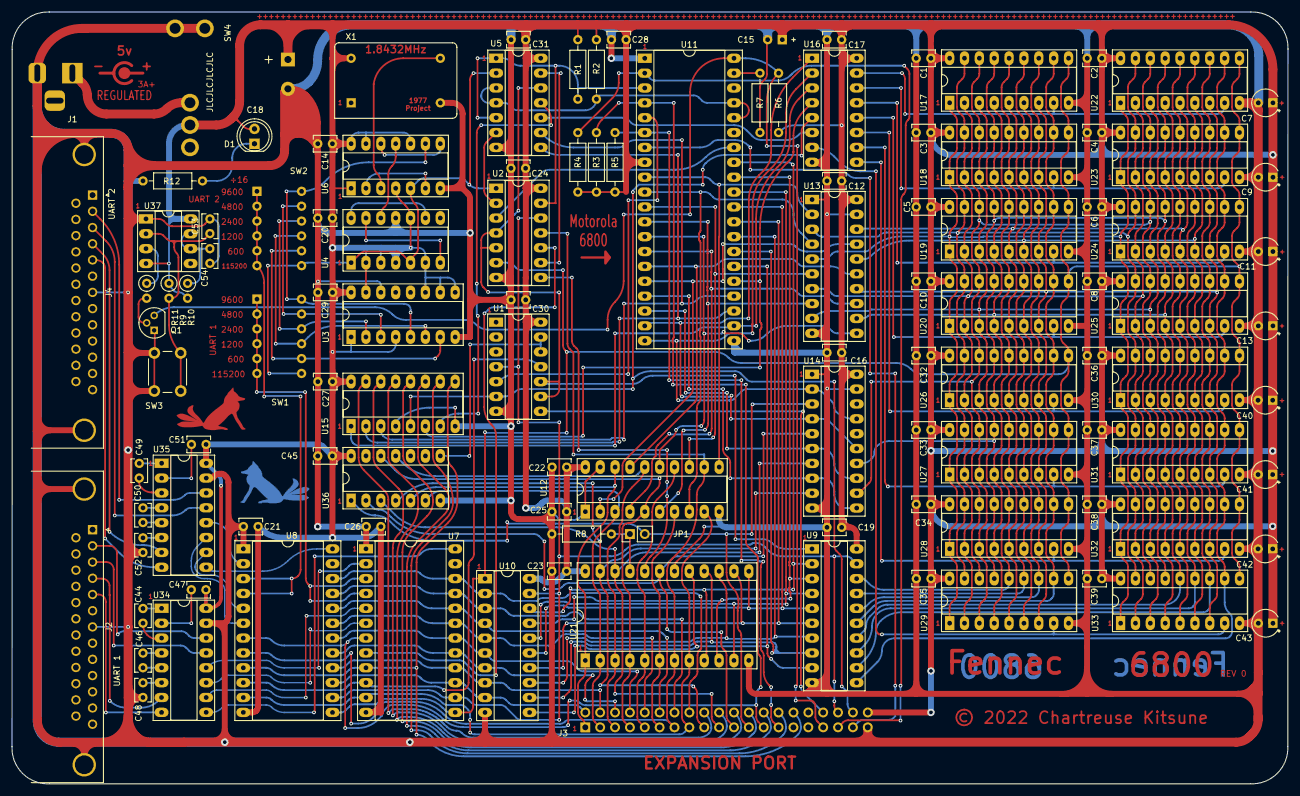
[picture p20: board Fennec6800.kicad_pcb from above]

Board: 2 copper layers, 218.0 x 131.9 mm, 115 parts (0 on the bottom side), 151 nets.

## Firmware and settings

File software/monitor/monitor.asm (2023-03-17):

; Fennec 6800 ROM monitor/mini-OS
; 2022/2023 Chartreuse 
;
; Usage:
;   All commands begin with a single letter, addr/ess are specified
;   as a full 16-bit (4 digit) hex value, and data as a full 8-bit
;   (2 digit) hex value. 
;   There is no backspace as input is processed immediately.
;   Invalid characters are silently ignored.
;   If a mistake is made, press ESC (Ctrl-[) to cancel the line and
;   return to the prompt.
;
;   Commands:
;    E - (E)xamine RAM, performs a hex dump from between two specified
;        addresses. The dash between addresses is NOT entered by the 
;        user but automatically by the monitor
;        eg.
;           E0000-0010
;        OUTPUT:
;	    0000: 00 20 08 20 00 00 DF 46 2C 0E 6F 36 7E FA 08 7E
;  
;    D - (D)eposit RAM, allows the user to enter hex data in memory 
;        starting at the specified address. After entering the address
;        the starting address will be displayed and the user can then
;        start entering bytes. After every byte (2 digits) entered a 
;        space will be returned showing the byte has been entered into
;        RAM. Every 16 bytes a newline and the next address will be 
;        displayed similar to the examine command. Press return or ESC
;        after you are done with entering bytes.
;	 eg. 
;            D0100
;            0100:12 34(ESC)
;            *
;    G - (G)oto address. Jumps to the specified address and resumes
;        execution at that point. This is performed as a subroutine 
;        jump, so if a program preserves the monitors stack, it can 
;        RTS back into the monitor.
;        eg.
;             G0100
;
;    R - (R)ecv XMODEM. Recieves a program using XMODEM (checksum) 
;        starting at the specified address. After specifying address
;        the user will be prompted to start the xmodem transfer on 
;        the remote computer. At this point start the transfer and when
;        completed you will be returned to the monitor prompt. If the
;        prompt is not visible, try hitting ESC to get it to reprint.
;        eg.
;             R0100
;             SEND FILE NOW
;             [user starts xmodem transfer in their terminal program]
;             *
;
;    S - (S)end XMODEM. Sends a block of memory using XMODEM (checksum)
;        from between the two specified addresses. After specifying the
;        second address, the user will be prompted to start an xmodem
;        recieve on their terminal. At this point, start the transfer
;        and when completed you will be returned to the monitor prompt.
;        If the prompt is not visible, try hitting ESC to get it to
;        reprint.
;        eg.
;             S0100-0200
;             RECV FILE NOW
;             [user starts xmodem recieve in their terminal program]
;             *
;
; Changelog
;-----------------------------------------------------------------------
; 0.3.2
;   Added AUX to device routine options (DEVIN/DEVOUT/DEVINNB)
; 0.3.1
;   Added option rom detection and execution
; 0.3 
;   Converted to changable I/O routine pointers in preparation for 
;   VTI board and other option roms to change the default console and
;   others.
;
; 0.2 Added XMODEM send and recieve
; 0.1 Initial version
;-----------------------------
	CPU 6800

;-----------------------------------------------------------------------
; Address constants
RAMTOP	EQU $1FFF	; Last address to try sizing till
			; $1FFF = Full 8kB system (16x 2114 sram)
MONSTK	EQU $00FF	; Monitor reserves first 256 bytes of RAM
PSTART	EQU $8000	; Start of peripheral block
ROMSPA	EQU $04		; Spacing between option ROMS to test at *256
ENDROM	EQU $E0		; Check all the way till EXP0
MAGIC	EQU $F10F	; Magic word for option ROMS
MAGIC0	EQU $F1
MAGIC1	EQU $0F

UART1	EQU $EFF0	; Onboard UART A (lower port)
UART2	EQU $EFF2	; Onboard UART B (upper port)

;-----------------------------------------------------------------------
; Constants
PROMPT	EQU '*'

; ASCII constants
SOH	EQU $01
EOT	EQU $04
ACK	EQU $06
NAK	EQU $15
ETB	EQU $17
ESC	EQU $1B

;-----------------------------------------------------------------------
; Option ROM setup
ROMSIG	EQU $F10F	; Signature to load ROM
ROMNLEN	EQU 10		; Length of ROM name
ROMOFF	EQU 16		; Code start byte of ROM

;-----------------------------------------------------------------------
; Variables
ADDRT	EQU $0000	; 2 - Temp address 
RAMKB	EQU $0002	; 1 - # of kB of ram
BYTET	EQU $0003	; 1 - Temp byte
ADDRP	EQU $0004	; 2 - printing address
TIMER	EQU $0006	; 2 - timer for delays
SEQ	EQU $0008	; 1 - Current block for XMODEM
CSUM	EQU $0009	; 1 - Current checksum for XMODEM
COUNT	EQU $000A	; 1 - Count of bytes (XMODEM)
LAST	EQU $000B	; 1 - Last acknowledgement (XMODEM)
; Controllable routines
;  - expect no reg preserved, result if any in A
CONTR	EQU $000C	; Start of controllable routines

CONIN	EQU CONTR	; 3 - JMP to GETC routine for console
CONOUT	EQU CONIN+3	; 3 - JMP TO PUTC routine for console
CONINNB	EQU CONOUT+3	; 3 - JMP to GETC (non-blocking) for console

AUXIN	EQU CONINNB+3	; 3 - JMP to GETC routine for aux 
AUXOUT	EQU AUXIN+3	; 3 - JMP TO PUTC routine for aux 
AUXINNB	EQU AUXOUT+3	; 3 - JMP to GETC (non-blocking) for aux

DEVIN	EQU AUXINNB+3	; 3 - JMP to device routine GETC
DEVOUT	EQU DEVIN+3	; 3 - JMP to device routine PUTC
DEVINNB	EQU DEVOUT+3	; 3 - JMP to device routine GETC (non-blocking)
			;  Device routines take device # in B
			;  0 = console, 1 = aux, 2 = uart a, 3 = uart b, 
			;  4+ rom or user defined
CONTRE	EQU DEVINNB+3	; End of controllable routines






;CONOUT EQU S0OUT
;CONIN EQU S0IN
;-----------------------------------------------------------------------
; Program
	ORG $F800	; 2kB ROM
START
	JMP ENTER
; Default controllable routines
DEFRT
	JMP S0IN
	JMP S0OUT
	JMP S0IN_NB
	JMP S1IN
	JMP S1OUT
	JMP S1IN_NB
	JMP DDEVIN
	JMP DDEVOUT
	JMP DDEVINNB
DEFRTE
DEFRTLEN EQU *-DEFRT


ENTER
	LDS #MONSTK	; Stack pointer
	JSR UARTINIT
	JSR CONTINIT	; Initialize controlable routines
	JSR RAMSIZE	; Size ram
	JSR FINDROM	; Find and run any option roms
	JSR BANNER
	JSR PRINTROM	; Find roms and print their names
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

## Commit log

2022-03-12 Initial commit, as produced rev0 (except some extra curves on traces)
    [77Project-B_Cu.gbl, 77Project-B_Mask.gbs, 77Project-B_Silkscreen.gbo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]
2023-03-17 Rename Project from 77Project. Add documentation
    [77Project-B_Cu.gbl, 77Project-B_Mask.gbs, 77Project-B_Silkscreen.gbo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]
2023-03-17 Updated manual and schematic
    [Fennec6800.kicad_sch]
2023-03-17 Added monitor assembly instructions. Updated DEV routines to include AUX
2023-03-17 Added assembled image
2023-03-17 Fixed link to AS assembler
2023-03-17 Reverted ref designator on PCB as bodge fixes are not yet done
    [Fennec6800.kicad_pcb]
2023-03-17 Added 62256 RAM adapter to repo
    [FennecRAMadapt-B_Cu.gbl, FennecRAMadapt-B_Mask.gbs, FennecRAMadapt-B_Paste.gbp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]

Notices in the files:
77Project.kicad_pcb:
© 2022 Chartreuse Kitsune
